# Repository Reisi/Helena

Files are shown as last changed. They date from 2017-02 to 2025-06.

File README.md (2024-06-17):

# Helena

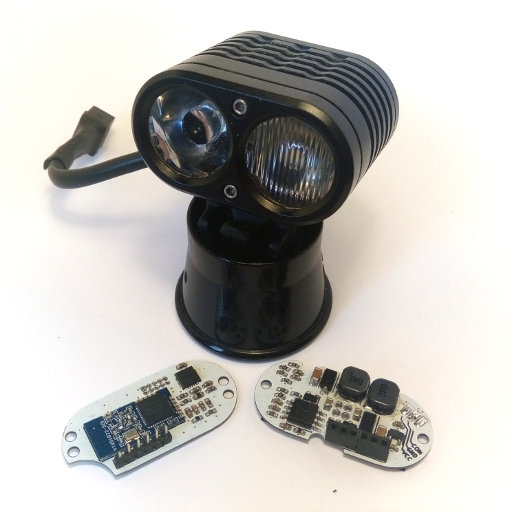
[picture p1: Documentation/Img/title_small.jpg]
Helena
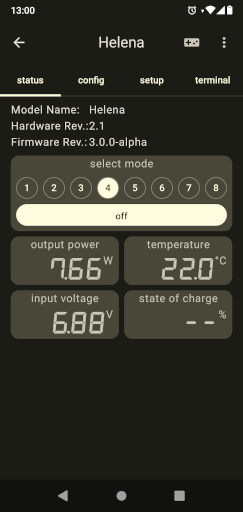
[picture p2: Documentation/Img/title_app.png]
app
 

Helena is an alternative driver for the Yinding or KD2 Headlight Cycling Lamp.

## Main Features

- Two independant 3A Step-Down current converters.
- Bluetooth connectivity for remote control, configuration and lamp-to-lamp connection.
- Linear power reduction at low battery and high temperature.
- Standby current less than 150µA.
- Supports 1 (one LED), 2 (one or two LEDs) or 3 (up to three LEDs in series) cell Li-Ion battery.
- An integrated motion sensor to control the output current to reduce glare when looking down.
- A multi-functional com pin, can be used for wired communication or an external button.

## License

This project is licensed under the BSD-2-clause License - see the [license.txt](license.txt) file for details

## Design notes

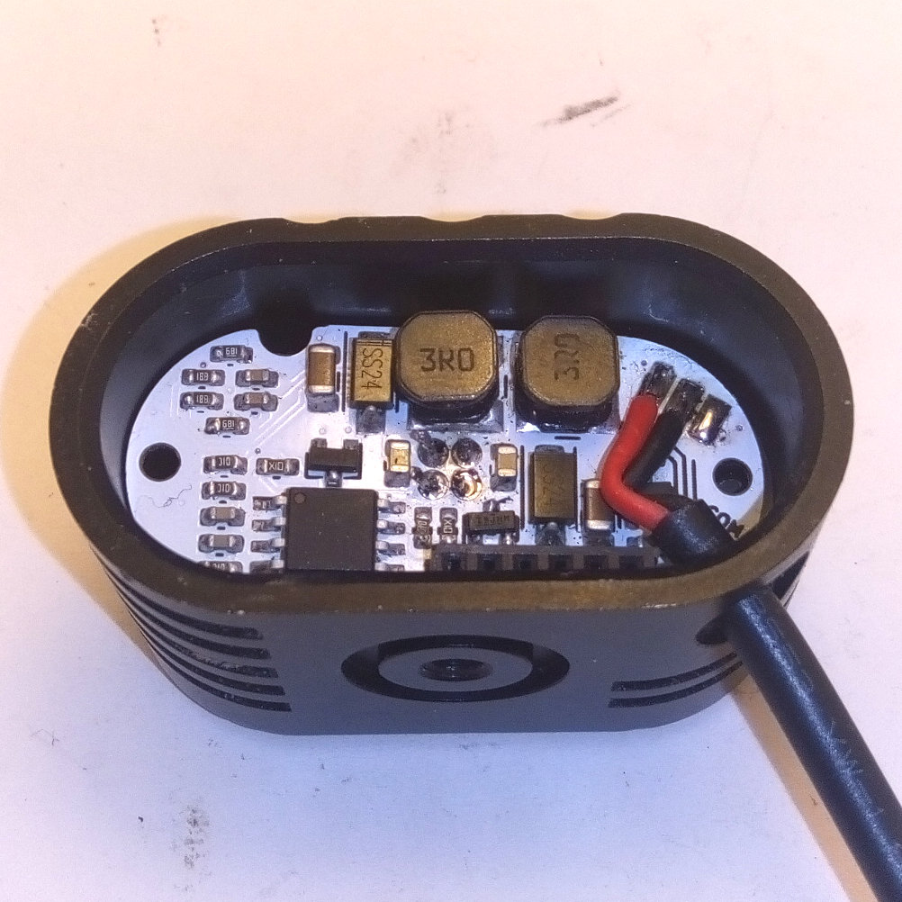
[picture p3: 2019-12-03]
Documentation/Img/inst_YDfull_04.jpg

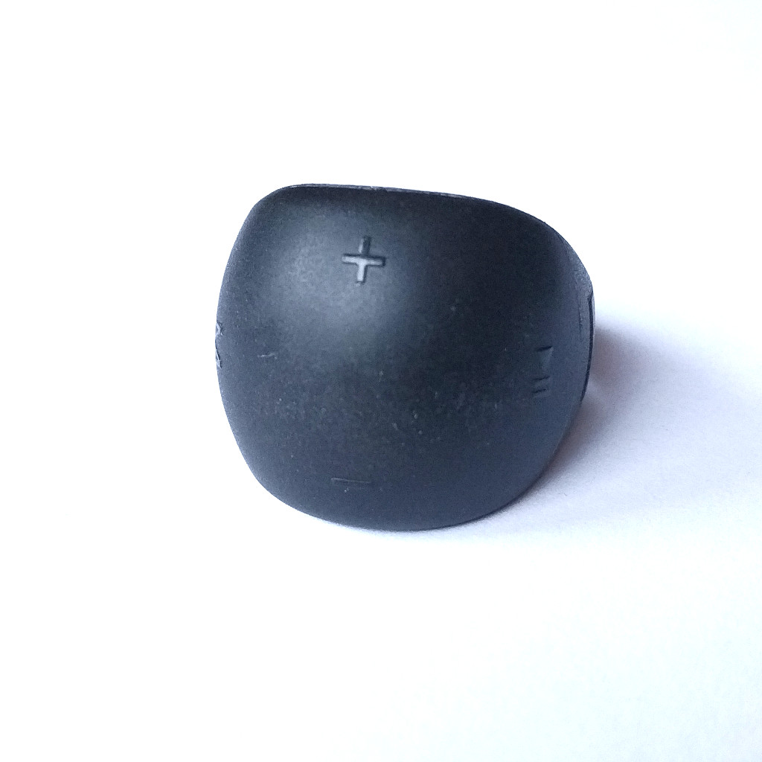
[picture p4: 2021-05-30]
Documentation/Img/R51.jpg

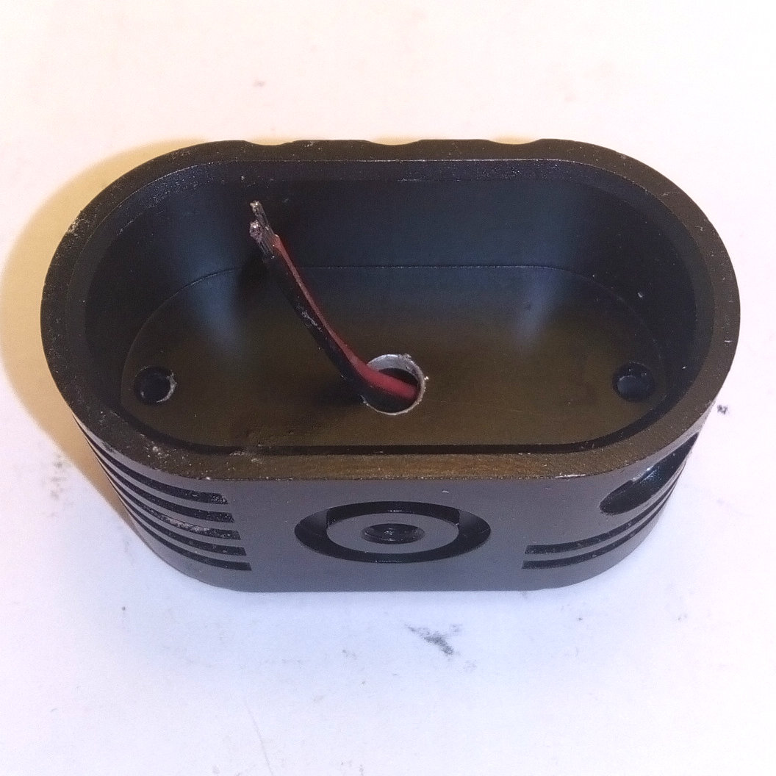
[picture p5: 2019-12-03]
Documentation/Img/inst_YD_01.jpg

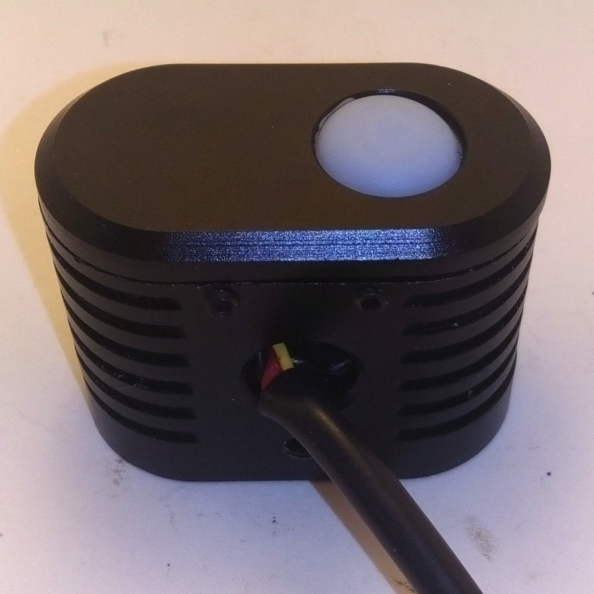
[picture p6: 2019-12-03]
Documentation/Img/inst_KD_06.jpg

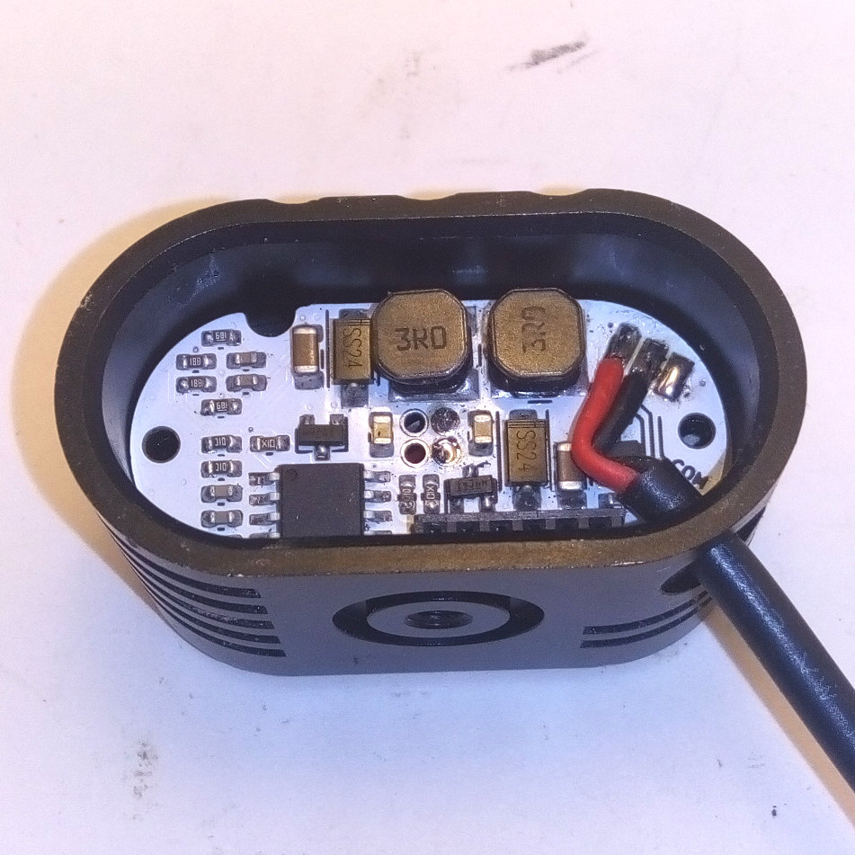
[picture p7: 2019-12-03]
Documentation/Img/inst_YD_03.jpg

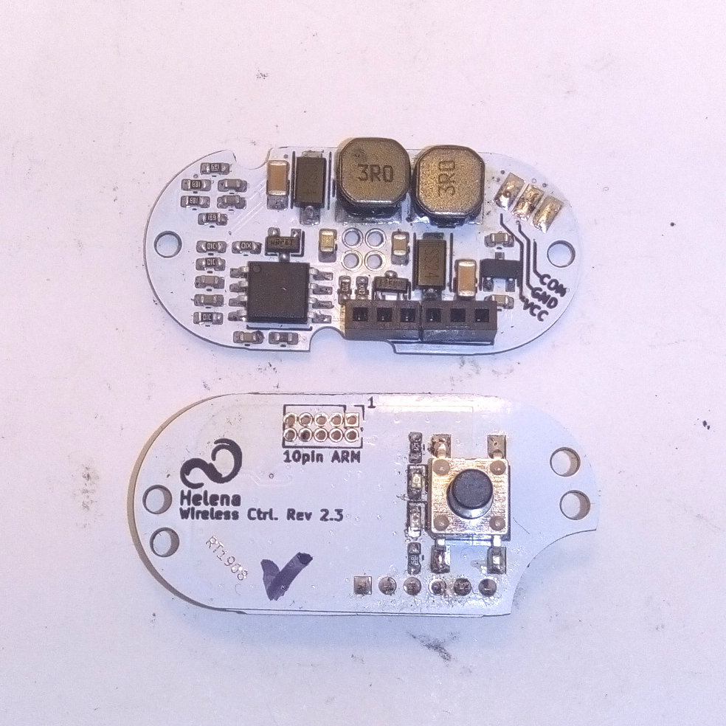
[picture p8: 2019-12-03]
Documentation/Img/inst_con_01.jpg

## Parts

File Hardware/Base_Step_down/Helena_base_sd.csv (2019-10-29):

Id | Designator | Package | Quantity | Designation | Reichelt ordering | MPN
1 | R10,R1,R6,R13,R14 | R_0603_1608Metric | 5 | 10k | RND 0603 1 10K
2 | Q3,Q4,Q6,Q7 | SOT-23 | 4 | IRLML0030 | IRLML 0030
3 | C2,C3,C7,C11,C13,C4 | C_0603_1608Metric | 6 | 100n | X7R-G0603 100N
4 | R4,R12 | R_0603_1608Metric | 2 | 680 | RND 0603 1 680
5 | D5 | SOT-23 | 1 | BAT54A | BAT 54A SMD
6 | L2,L1 | Choke_SMD_Fastron_242418_FPS | 2 | 3u-18 | L-242418FPS 3,0µ
7 | U3 | SOIC-8_5.23x5.23mm_P1.27mm | 1 | ATTINY85-S | ATTINY 85-20 SU
8 | R9,R2,R7 | R_0603_1608Metric | 3 | 10 | RND 0603 1 10K
9 | C10,C12 | C_0603_1608Metric | 2 | 2u2/16 | X5R-G0603 2,2/16
10 | Q1,Q5 | SOT-23 | 2 | BC857C | BC 857C SMD
11 | C8,C6 | C_1206_3216Metric | 2 | 10u/16 | KEM X7R1206 10U
12 | P2,P3,P1 | 1,5x3mm_SMD | 3 | CONN_01X01
13 | REF**,REF** | MountingHole_2.2mm_M2 | 2 | MountingHole_2.2mm_M2
14 | P4 | Pin_Header_Straight_1x06_2.00_Pitch | 1 | CONN_01X06 | MPE 156-1-007
15 | P5,P6,P7,P8 | MILLMAX_5660 | 4 | CONN_01X01 |  | 0660-0-15-15-30-27-10-0
16 | G*** | Helena_5,0x4,1mm | 1 | LOGO
17 | C1,C14 | C_0603_1608Metric | 2 | 22n | X7R-G0603 22N
18 | C5,C9 | C_0805_2012Metric | 2 | 10u/16 | X5R-G0805 10/16
19 | D1,D4,D7 | SOT-23 | 3 | 3V3 | SMD ZD 3,3
20 | D2 | SOT-23 | 1 | 18V | SMD ZD 18
21 | D3,D6 | D_SMA | 2 | SK24A | SK 24A SMD
22 | FB1 | L_0603_1608Metric | 1 | FB | BLM18PG 331
23 | Q2 | SOT-23 | 1 | BSS138 | BSS 138 SMD
24 | R3 | R_0603_1608Metric | 1 | 4k7 | RND 0603 1 4,7K
25 | R5,R11 | R_0603_1608Metric | 2 | 1k5 | RND 0603 1 1,5K
26 | R8 | R_0603_1608Metric | 1 | 330 | RND 0603 1 330
27 | U1 | MSOP-8_3x3mm_P0.65mm | 1 | MCP6482 | MCP 6482-E/MS
28 | U2 | SOT-23W | 1 | MCP1703CB | MCP 1703T-3302E

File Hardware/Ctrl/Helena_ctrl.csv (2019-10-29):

Id | Designator | Package | Quantity | Designation | Reichelt ordering | MPN
1 | SW1 | JTP-1138EM | 1 | SW_PUSH | TASTER 9314
2 | U1 | QFN-24-1EP_4x4mm_Pitch0.5mm | 1 | MPU-6050 |  | MPU-6050
3 | A1 | WT51822-S4AT | 1 | nrf51822-04AT_Module |  | WT51822-S4AT
4 | REF**,REF**,REF**,REF** | MountingHole_2.2mm_M2 | 4 | MountingHole_2.2mm_M2
5 | G*** | Helena_5,0x4,1mm | 1 | LOGO
6 | C1 | C_0603_1608Metric | 1 | 2u2/16 | X5R-G0603 2,2/16
7 | C2,C13,C15,C16 | C_0603_1608Metric | 4 | 100n | X7R-G0603 100N
8 | C14 | C_0603_1608Metric | 1 | 10n | X7R-G0603 10N
9 | C17 | C_0603_1608Metric | 1 | 2n2 | X7R-G0603 2,2N
10 | D1 | D_0603_1608Metric | 1 | LED_RED | LED EL 0603 RT
11 | D2 | D_0603_1608Metric | 1 | LED_BLUE | LED EL 0603 BL
12 | FB1,FB2 | L_0603_1608Metric | 2 | FB | BLM18PG 331
13 | J1 | PinHeader_1x06_P2.00mm_Vertical | 1 | CONN_01X06 | MPE 150-1-010
14 | J2 | PinHeader_2x05_P1.27mm_Vertical | 1 | CONN_02X05
15 | R1 | R_0603_1608Metric | 1 | 470k | RND 0603 1 470K
16 | R2 | R_0603_1608Metric | 1 | 100k | RND 0603 1 100K
17 | R3,R5 | R_0603_1608Metric | 2 | 1k5 | RND 0603 1 1,5K
18 | R4 | R_0603_1608Metric | 1 | 680 | RND 0603 1 680
19 | R7 | R_0603_1608Metric | 1 | 120 | RND 0603 1 120

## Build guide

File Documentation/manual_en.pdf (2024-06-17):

# Helena

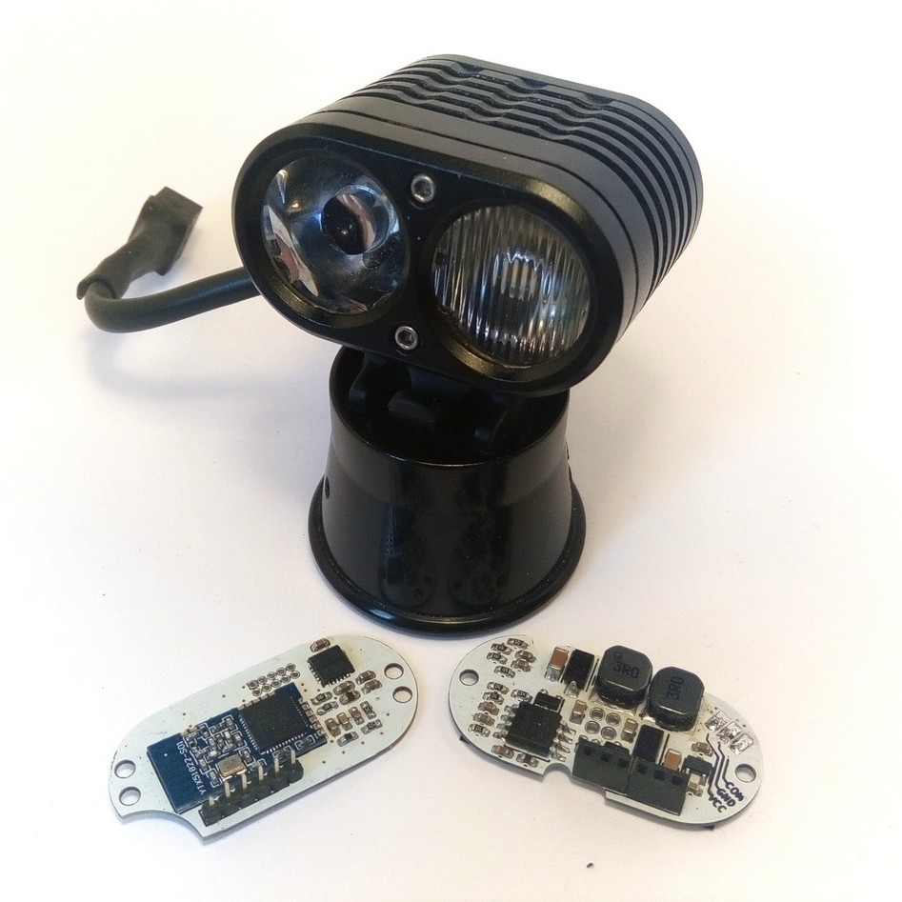
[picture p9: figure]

# User Manual

Helena User Manual

## 1 Preface

Helena is an alternative driver for the popular Yinding or KD2 Headlight Cycling Lamp with following features:
- Two independent 3A Step-Down constant current sources, each capable of driving two white LEDs in series. The intended setup is one Cree XHP50 LED equipped with a flood optic and one Cree XHP35 6V equipped with a spot optic.
- Integrated motion sensor to drive the LEDs in dependency of the head inclination, resulting a nearly constant brightness level, no matter if you're looking down or straight forward.
- Bluetooth interface for wireless remote control, lamp daisy-chaining and Smartphone based configuration.
- Integrated temperature regulation to prevent lamp from overheating.
- Smooth output power reduction when battery is low.
- Low standby current (less than 100µA).
- Works with input voltages between 3V and 4.25V (only 1 LED per current source), 6V and 8.5V and between 9V and 12.75V (max. output current is limited to 2.4A).

2/22

Helena User Manual

## Index

3/22

Helena User Manual

## 2 Installation

## 2.1 Connections

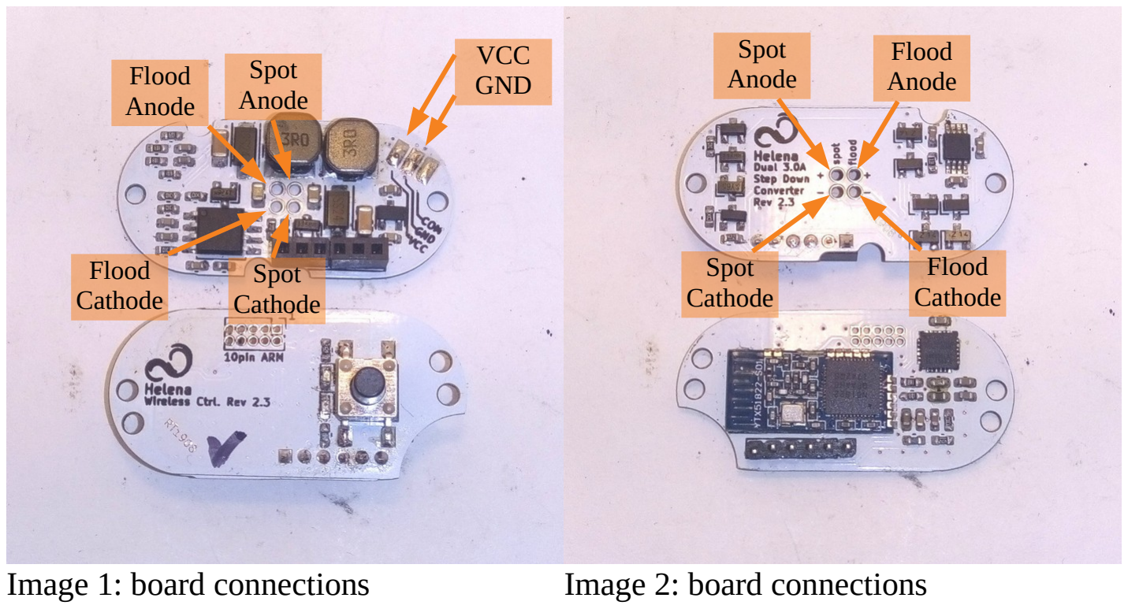
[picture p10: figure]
Flood Cathode; Flood Anode; Spot Cathode; Spot Anode; VCC GND

4/22

Image 1: board connections | Image 2: board connections

Helena User Manual

## 2.2 Driver Swap for KD2

Step 1.Disassemble lamp and remove old driver. Mount LED board witch the

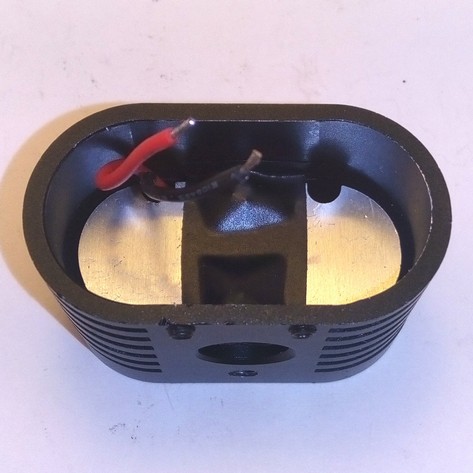
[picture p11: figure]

notches facing to the top and route both cables through the left one. Then cut the cables to a length of 20-25mm and cover the screws with electric tape.

Step 2.Connect the LED cables to the spot driver output of the LED driver. Route the cables as shown in the image.
Step 3.Attach the power cable (and optionally the communication line). Route the cables along the board-to-board connector and use the notch next to it to lead it through the opening.

5/22

Image 3: LED board
preparations

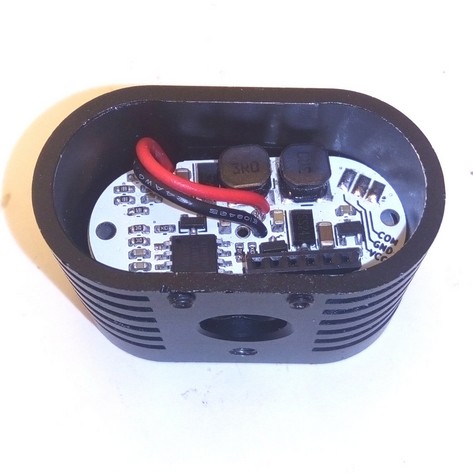
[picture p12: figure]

Image 4: LED connection

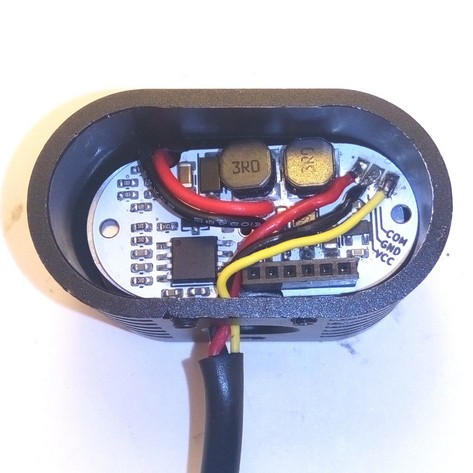
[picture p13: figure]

Image 5: power cable
routing

Helena User Manual

Step 4.Mount the controller board to the lid.
Step 5.Put a pair of tweezers, zip ties, toothpicks or a similar object between the LED- and driver board to lift it a couple of millimeters, then put the lid on and.
Step 6.When the connector fits properly, remove the tweezers, close the lid and you are done.

6/22

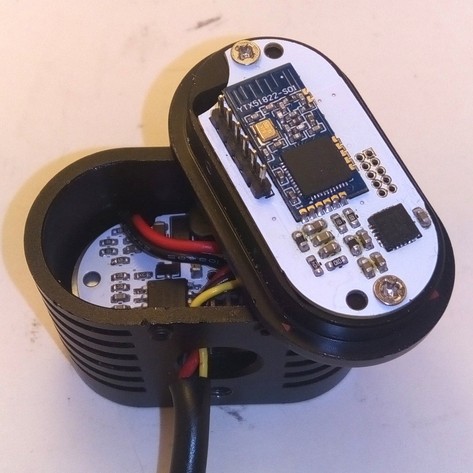
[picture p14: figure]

Image 6: mounted
Controller board

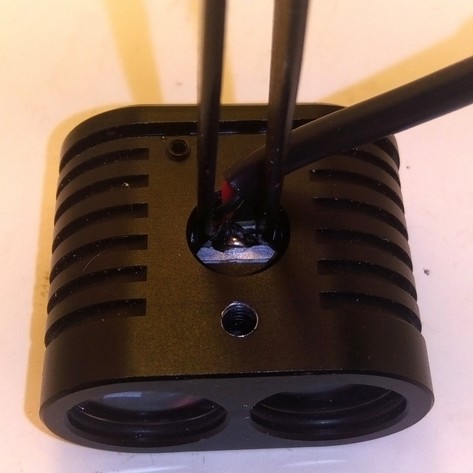
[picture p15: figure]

Image 7: Lift driver board for proper connection

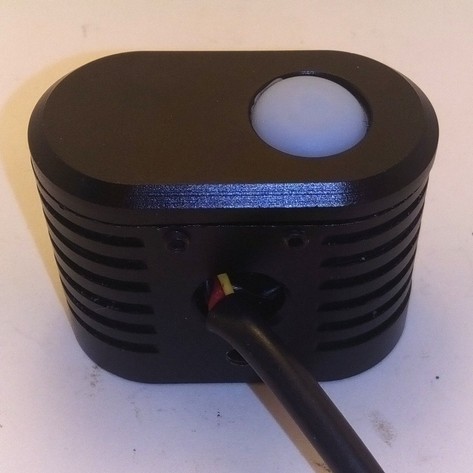
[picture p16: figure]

Image 8: closed lid

Helena User Manual

## 2.3 Driver Swap for Yinding

Step 1.Disassemble lamp and remove old
driver. Cut the cables to a length of 20-
25mm.
Step 2.Attach the power cable (and optionally the communication line) Don’t forget to run the cable through the opening in the lamp body.
Step 3.Now attach the cables from the LED board to the spot output. Connect them from the bottom side.

7/22

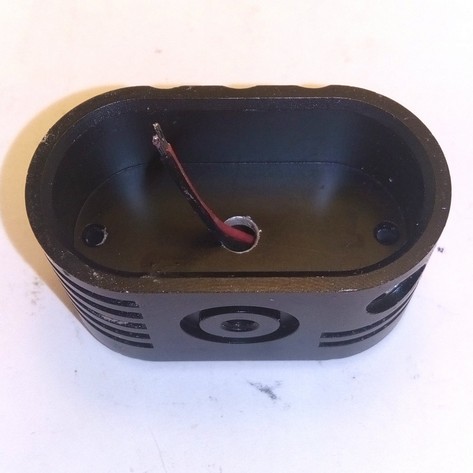
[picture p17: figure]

Image 9: prepared LED
cables

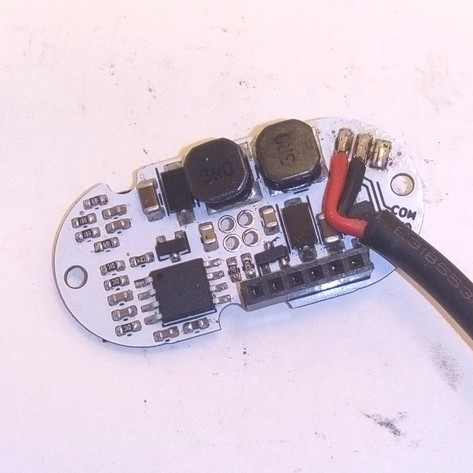
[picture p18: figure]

Image 10: attached power
cable

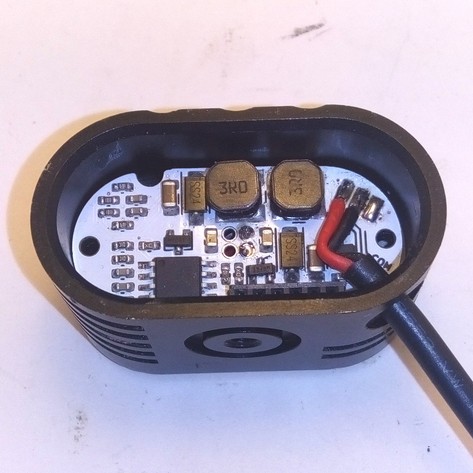
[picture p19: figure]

Image 11: attached LED
cables

Helena User Manual

Step 4.Mount the controller board to the lid.
Step 5.Close the lid and reassemble the lamp.

8/22

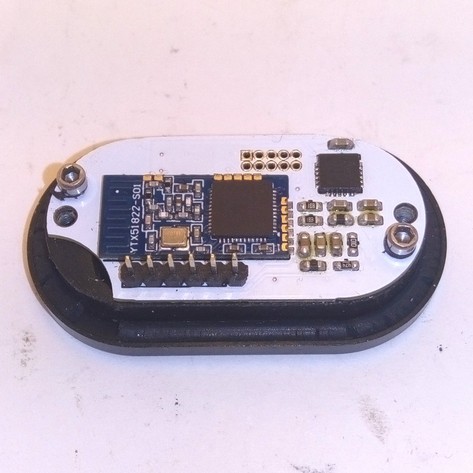
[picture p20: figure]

Image 12: mounted
Controller board

Helena User Manual

## 2.4 Full conversion for Yinding

Step 1.Prepare LED boards by attaching
cables and cutting them to a length of
25-30mm.
Step 2.Attach the power cable (and optionally the communication line) Don’t forget to run the cable through the opening in the lamp body.
Step 3.Route the LED boards cables through the inner hole.

9/22

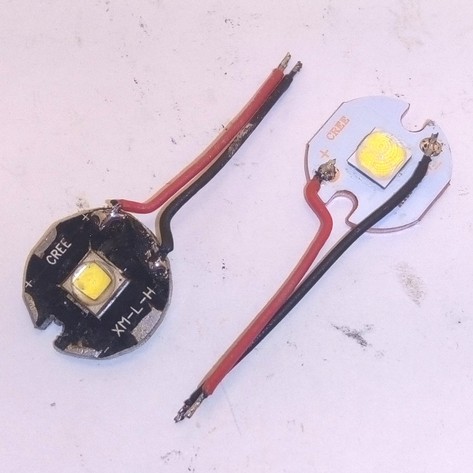
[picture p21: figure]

Image 13: prepared LED
boards

Image 14: attached power
cable

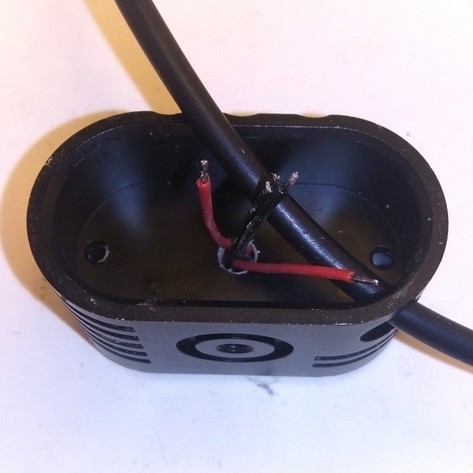
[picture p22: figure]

Image 15: cable routing

Helena User Manual

Step 4.Now attach the cables from the bottom

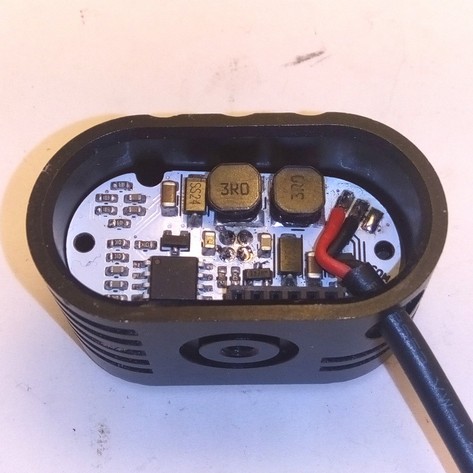
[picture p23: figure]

side. Solder the cables of the XHP50 to the flood output and the cables of the XM-L to the spot output.

Step 5.Mount the controller board to the lid and close the lid.
Step 6.Flip the lamp around and tighten the screws to secure the lid and LED

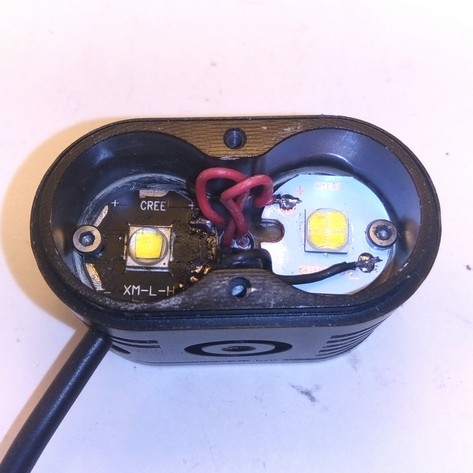
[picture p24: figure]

boards. Position the XHP50 board a bit to the top and the XM-L board a bit to the bottom.

10/22

Image 16: attached LED
boards cables

Image 17: mounted
Controller board

Image 18: LED boards
alignment

Helena User Manual

Step 7.Insert the lenses and use some spacers to tilt the spot lens upwards and the flood lens downwards. The spacers should have a height of 0.7-1.0mm, a quartered O-Ring works fine.
Step 8.Finally mount the lens cover.

11/22

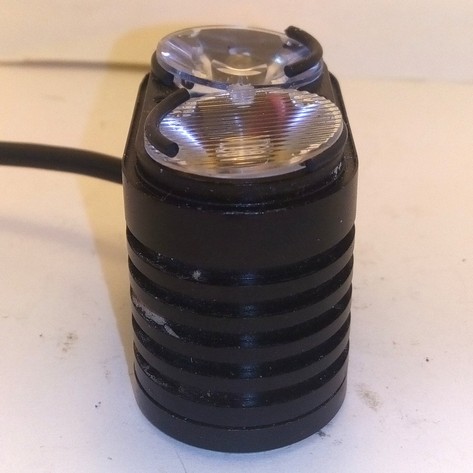
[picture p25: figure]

Image 19: tilted lenses

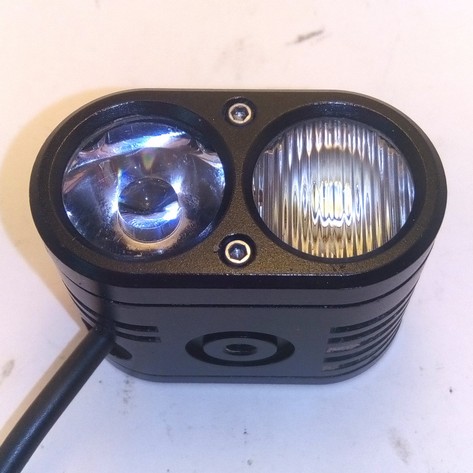
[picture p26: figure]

Image 20: reassembled

Helena User Manual

## 3 Usage

## 3.1 Modes and Groups

Helena has 8 individual configurable modes, which can be organized in different groups.

### 3.1.1 Preferred Mode

One of the 8 available modes can be selected as the preferred mode. If no mode is selected to be the preferred mode, the lamp will shut off whenever the preferred mode is selected. If one mode is selected as the preferred mode the lamp will shut off, if it already is in the preferred mode. Otherwise it will jump to the preferred mode.

### 3.1.2 Temporary Mode

One of the 8 available modes can be selected as a temporary mode. If a mode is selected as temporary mode, it is possible to jump directly into this mode. When leaving the mode, Helen jumps back to the previously used mode.

### 3.1.3 Off Mode

One of the 8 available modes can be selected as the off mode. If a mode is selected as off mode, this mode will be used when the lamp is shut off. When the lamp enters stand-by mode (after three minutes without movement) it will completely shut off.

12/22

Helena User Manual

## 3.2 Remote Connection

Helena can manage up to 3 connections, 2 as a central (e.g. a remote control or another lamp) and 1 as peripheral (e.g. a smart phone or another lamp).
Although it is possible to pair with several remote controls, it is not possible to connect to more than one remote control simultaneously. If two lamps are connected to each other, the lamp with the peripheral connection will break its connection with a remote control and won’t reconnect as long as it is connected with the other lamp.

### 3.2.1 Central connection

To initiate a connection as central (e.g. if you want to connect to a remote control or initiate a central connection with another lamp), you have to
- shut of Helena,
- make sure, that all other unwanted compatible devices are shut of or out of range,
- press Helena’s button for at least 2 sec.
Helena will indicate the search process with a fast blinking blue status LED. As soon as a connection is established the blue status LED will be constantly on. If no device is found within 30 sec. the lamp will stop searching and starts a 30 sec. window where it is open for peripheral connections (see next chapter).

13/22

Helena User Manual

This procedure is only necessary for the initial connection. The lamp will store all necessary information and automatically reconnect if the device is available.

### 3.2.2 Peripheral connection

To initiate a connection as peripheral (e.g. if you want to connect to a smartphone or initiate a peripheral connection with another lamp), you have to
- shut of Helena,
- make sure, that all other unwanted compatible devices are shut of or out of range,
- press Helena’s button for at least 2 sec until the blue led blinks fast,
- wait 30 sec until the blue led stops fast blinking.
Now you can start the connection procedure on the central device. This procedure is only necessary for the initial connection. The lamp will store all necessary information and you can establish future connection as soon as Helen is powered on.

## 3.3 Button Control

There are 4 button control commands:
- next mode:
This command jumps to the next mode.
If the ignore flag for this mode is selected, it will be skipped.

14/22

Helena User Manual

If the last mode within a group is reached, it will roll over to the first mode.
If the light is currently off it jumps to the first mode.
- next group:
This command jumps to the next group.
If the group only contains ignored modes, it will be skipped. If the current group is the last group, this command will jump to the first group.
If the light is currently off, it jumps to the first mode in the second group.
- preferred mode:
If the preferred mode is not set, the light will shut off.
If the preferred mode is set, the light will jump directly to the preferred mode.
If the light is already in the preferred mode, it will shut off.
- temporary mode:
If the temporary mode is set, the light will jump into the temporary mode and jumps back to the previous mode.

### 3.3.1 Integrated button

- short click:
next mode command
- long click:
next group command

15/22

Helena User Manual

- press and hold > 2 sec., light is on: preferred mode command
- press and hold > 2 sec., light is off:
initiate connection procedure
hold button again for 2 sec. to delete all bluetooth bonding data
- press and hold > 10 sec., light is off:
initiate a factory reset

### 3.3.2 External button (if available)

- short click:
next mode command
- long click:
next group command
- press and hold > 2 sec.:
preferred mode command

### 3.3.3 Xiaomi Yi remote control

- main button, short click:
next mode command
- main button, press and hold > 0.5 sec.:

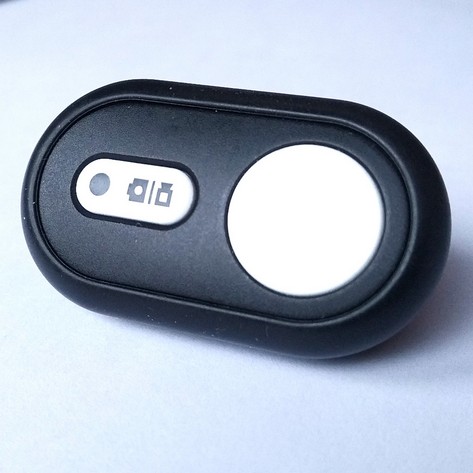
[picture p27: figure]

enter temporary mode as long as button is pressed
- secondary button, short click:
next group command

16/22

Image 21: Xiaomi Yi RC

Helena User Manual

- secondary button, press and hold > 0.5 sec.: preferred mode command

### 3.3.4 Pearl/Auvisio remote control

- next track button, short click:
next mode command
- previous track button, short click:
previous mode command
- volume up button, short click: next group command
- volume down button, short click: previous group command
- play/pause button, short click:
preferred mode command

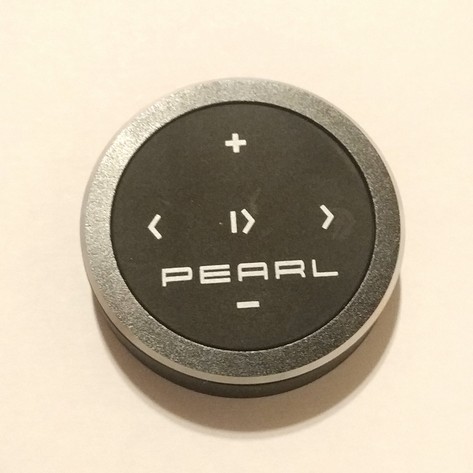
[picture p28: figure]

## 3.4 Remote Synchronization

If Helena is connected to another lamp, both lamps will synchronize their current mode. This means if one light receives a button command, it will change its mode according to the description in the previous chapter and then relay this new mode (the number, not the configuration!) to the other lamp.
This lamp will then also jump into this mode, nevertheless if this mode is used or not. With this behavior it is possible to generate configurations where one lamp is on and the other not.

17/22

Image 22: Pearl/Auvisio
remote

Helena User Manual

## 3.5 Status LED

Helena is equipped with a red and blue status LED, which is visible through the transparent button cap.
The blue LED gives information about the wireless connection. If is on, Helena is connected to a remote or another lamp. A fast blinking indicates, that Helena is searching for any compatible device. A slow blinking blue LED indicates, that Helena is searching for a already known device.
The red on turns on whenever the output is limited due to high temperature or dropping input voltage.
When Helena enters standby mode, the Status LED is shut off for minimum current consumption (but an established connection or the scanning for a known device will not be stopped).

18/22

Helena User Manual

## 4 Configuration

## 4.1 Connecting with the App

To connect to your lamp plug in the battery,
open the App on your phone and press the
SEARCH button. The App will then search and connect to all compatible lamps in range. Tap on the the light you want to configure.

19/22

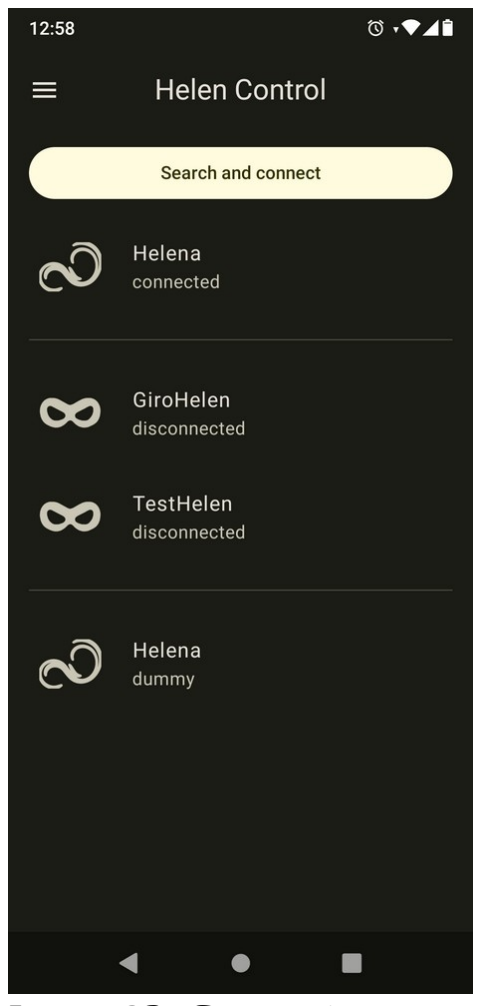
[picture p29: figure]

Image 23: Connecting

Helena User Manual

## 4.2 Light status

The STATUS page
gives you information
about the current state
of the lamp.
If you tap at the control
icon in the top bar you
can also select any of
the light modes or shut
it off.
You can also switch
between the Expert
Mode and two profiles
for easier configuration
and setup (Helena for
a full conversion, or
SimpleHelena if

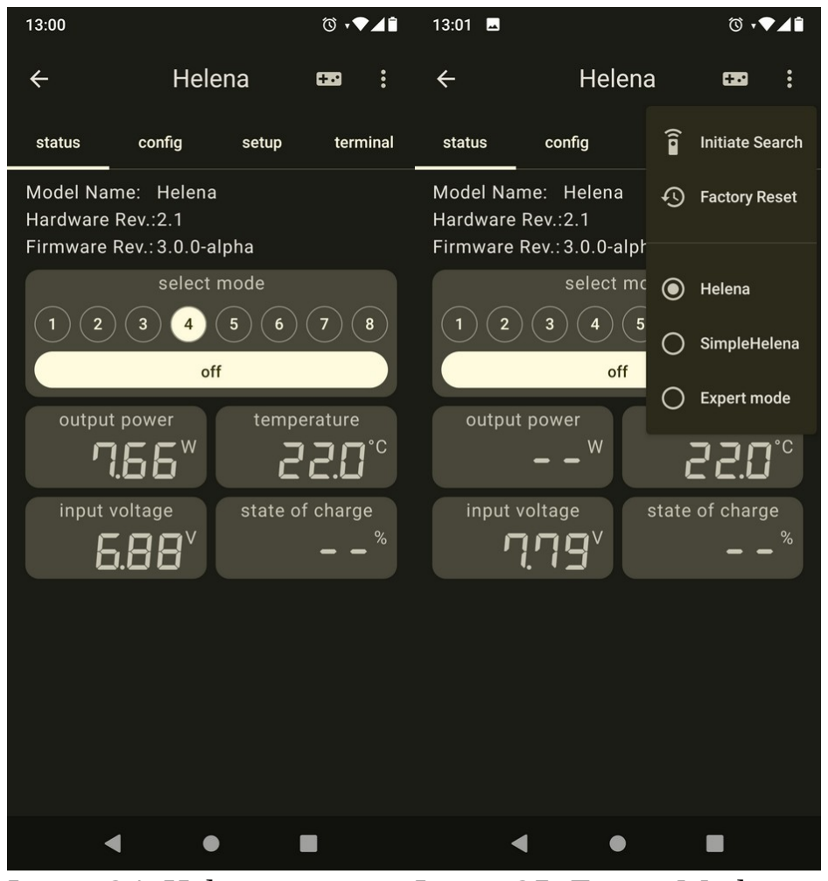
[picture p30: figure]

you just swapped the driver)

20/22

Image 25: Expert Mode or
profile selection

Image 24: Helena status

Helena User Manual

## 4.3 Configuration

On the CONFIG page
you see an overview of
your modes and the

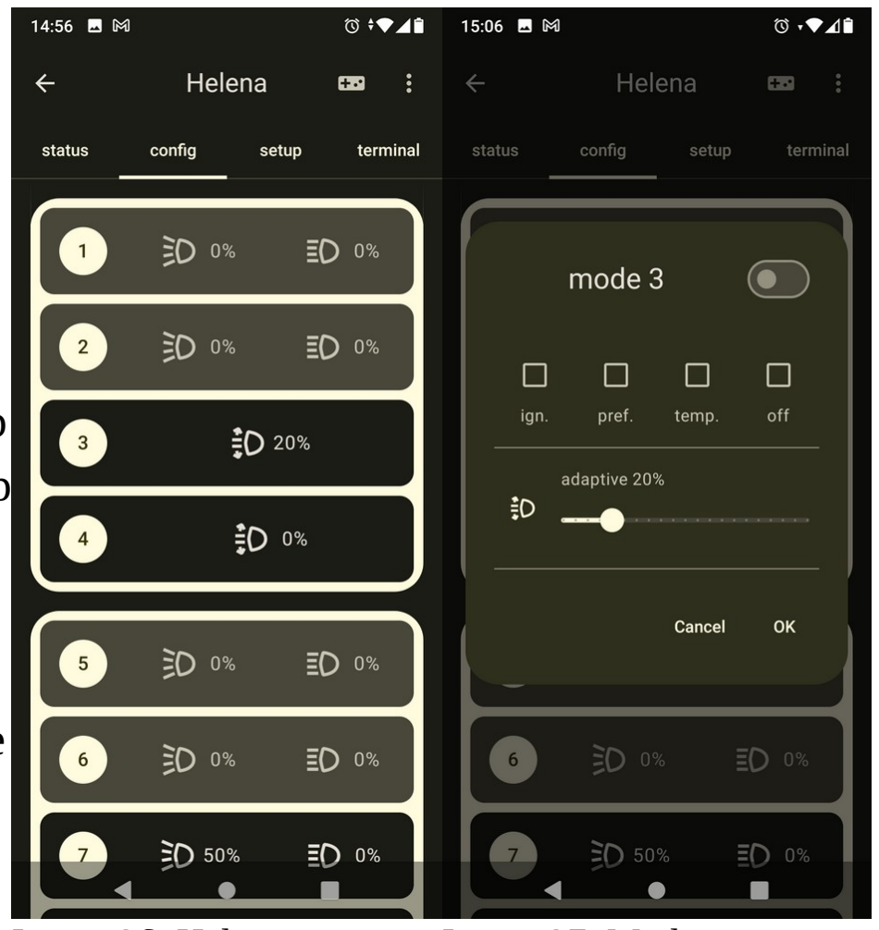
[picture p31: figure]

group arrangements. To
change the group
arrangement simply
drag and drop the group
dividers. To add a group
you can drag and drop
from the top or bottom.
To change a mode
configuration tap on the
mode. There you can
select if the mode
should be ignored, used
as preferred, temporary
or off mode, you can select the intensity of the light and if the motion sensor should be used for to adjust the light depending on your head inclination.

21/22

Image 27: Mode
configuration

Image 26: Helena
configuration

Helena User Manual

## 4.4 Setup

On the SETUP page you can select how to use the the communication pin. If you selected the Expert Mode you can also specify the setup of both LED channels.

22/22

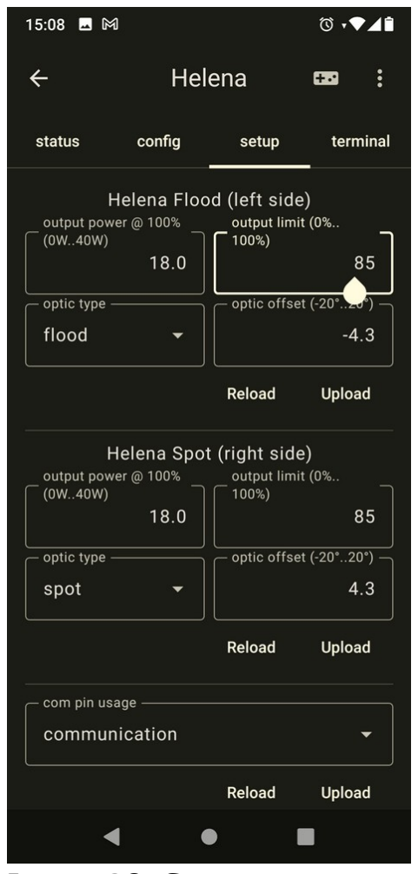
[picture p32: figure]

Image 28: Setup

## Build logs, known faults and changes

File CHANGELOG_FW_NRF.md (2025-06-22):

# Changelog
All notable changes to the NRF51 firmware will be documented in this file.

The format is based on [Keep a Changelog](https://keepachangelog.com/en/1.0.0/)

## [3.0.1] - 2025-06-22
### Fixed
- mode relay result in hard fault if made change initiated through com interface.
  (temporarily fixed by decreasing com interrupt level, but better solution is to 
  keep interrupt level high and relay in main context)
- increased transmit power

### Known Issues
- bootloader disconnects at about 20% when started in main application

## [3.0.0-alpha] - 2024-06-17
### Changed
v3 is not a continued development, it is the nrf52 based helen project ported to the nrf51.
- added support for a second central connection
- channels can be configured completely individual, making the need for different firmware variants obsolete
- the com pin can alternatively be used for an external button
- limiter is now prioritized, with spot having a higher priority as the flood

## [2.3.1] - unreleased
### Added

### Changed
- mode changes from com will now be relayed

### Removed

### Fixed
- fixed wrong version build format
- database discovery will be restarted if first attempt is busy

### Known Issues
- daisy chain: if quickly changing mode twice, the second change may not be 
  executed by the remote lamp.

## [2.3.0] - 2022-07-24
### Added
- support for billy base led driver
- bonding required to change settings (only for release)
- support for avisio/pearl remote control

### Changed
- group size can be configured individually

### Removed

### Fixed
- missing length checking for debug commands
- false decoding for com master messages
- going backwards to modes and groups malfunction
- missing line breaks in debug calibration section
- watchdog reset if transferring long error log over BLE

### Known Issues
- daisy chain: if quickly changing mode twice, the second change may not be 
  executed by the remote lamp.

## [2.2.1] - 2021-05-30
### Added

### Changed

### Removed

### Fixed
- wrong placed error check on data storage
- billina not transmitting correct high beam intensity
- features incomplete
- rounding error at intensity converting
- wrong error code if sensor offset not done yet

### Known Issues
- daisy chain: if quickly changing mode twice, the second change may not be 
  executed by the remote lamp.

## [2.2.0] - 2021-05-02
### Added
- improved status led, blue blinking while scanning, red and blue active works
  now for HWREV22 and HWREV23, too.
- added battery SOC and taillight power to measurement notification
- temporary mode
- hold button for 10 sec. (from off state) will initiate factory reset
- SOS mode for Helena, to enter press button for 10 sec. from an active mode
- support for 1- and 3-cell li-ion batteries.

### Changed

### Removed

### Fixed
- BLE_GATT_STATUS_ATTERR_CPS_PROC_ALR_IN_PROG leading to reset
- automatic led count detection might deliver wrong led count

### Known Issues
- daisy chain: if quickly changing mode twice, the second change may not be 
  executed by the remote lamp.

## [2.1.0] - 2021-04-18
### Added
- support for R51 "The Lord of Rings" Remote Control

### Changed
- behavior of preferred mode
- removed service discovery for HID service and replaced it with hardcoded 
  presets.

### Removed

### Fixed
- several fixes concerning data storage

### Known Issues
- automatic led count detection might deliver wrong led count

## [2.0.2] - 2021-03-30
### Added

### Changed

### Removed

### Fixed
- mode request not using full message length
- wrong flags in measurement data

### Known Issues
- automatic led count detection might deliver wrong led count

## [2.0.1] - 2021-03-28
### Added

### Changed

### Removed

### Fixed
- changing between helena and billina firmware now possible without loss of 
  settings

### Known Issues
- automatic led count detection might deliver wrong led count

## [2.0.0] - 2021-03-25
### Added
- added build target for "Billy" mode, a setup especially for bike lights 
  without pitch compensation, but separate driver current for low and high 
  beam.

### Changed
- light control services was modified and extended to meet requirements for 
  bicycle light

### Removed

### Fixed
- update from version 0.X will not end in an error loop anymore

### Known Issues
- when changing for helena to billina firmware (and vice versa) settings will 
  reset to defaults
- automatic led count detection might deliver wrong led count

## [1.1.0] - 2020-03-11
### Added
- re-implemented reset survive (lamp keeps its mode even if it is reset by 
  watchdog)
- release version

### Changed
- reworked debug interface

### Removed

### Fixed

### Known Issues
- Update from version 0.X might result in an infinite error loop. 
  Workaround: flash back to old firmware and perform factory reset, then update
  will work
- automatic led count detection might deliver wrong led count

## [1.0.0] - 2019-12-03
### Added
- this changelog
- Daisy chain feature, lamp cannot only connect to remote but to other light, 
  too. Changes to another mode (either by remote or button) are relayed to 
  other connected lamps, this work bidirectional
- expanded light setups and added the ability to control an external taillight
  and brake indicator using the wired communication interface
- automatic wake-up from STANDBY mode when moving to speed up (re-)connection 
  to remote
- preferred mode added, when set to a valid mode, lamp will start into this 
  mode and, if shutdown via remote, return to this mode first
- option to calibrate driver board over debug interface

### Changed
- Switched mode configuration from enumeration to flag based setup
- changed temperature limiter to start later at 59°C (previous started at 47°C)
- changed voltage limiter to a two slope curve, to provide more output power at
  low battery temperatures
- user manual and quick start guide are adapted to flag based setup 
  configuration
- indicator leds are shut off in STANDBY mode to minimize current consumption
- debug interface changed, no "get error log" message necessary anymore, log is
  enabled automatically with enabling notifications

### Removed

### Fixed
- device will not bond to remote (had no effect, because remote initiated 
  bonding)
- garbage collection not working properly resulting in a lockup where no more 
  write operations are working.

### Known Issues
- Update from version 0.X might result in an infinite error loop. 
  Workaround: flash back to old firmware and perform factory reset, then update
  will work

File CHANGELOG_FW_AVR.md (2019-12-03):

# Changelog
All notable changes to the AVR based LED driver board firmware will be 
documented in this file.

The format is based on [Keep a Changelog](https://keepachangelog.com/en/1.0.0/)

## [Unreleased]
### Added
### Changed
### Removed
### Fixed
### Known Issues

## [1.2] - 2019-12-03
### Added
- this changelog
- calibration option through I2C interface

### Changed

### Removed

### Fixed

### Known Issues

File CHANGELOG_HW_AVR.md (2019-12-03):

# Changelog
All notable changes to the AVR based LED driver board hardware will be 
documented in this file.

The format is based on [Keep a Changelog](https://keepachangelog.com/en/1.0.0/)

## [Unreleased]
### Added
### Changed
### Removed
### Fixed
### Known Issues

## [2.3] - 2019-12-03
### Added
- this changelog
- added notches for optimized cable routing for KD2 lamps
- changed to IPC-7351B footprints

### Changed

### Removed

### Fixed

### Known Issues

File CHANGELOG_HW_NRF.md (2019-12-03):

# Changelog
All notable changes to the NRF51 based controler driver board hardware will be 
documented in this file.

The format is based on [Keep a Changelog](https://keepachangelog.com/en/1.0.0/)

## [Unreleased]
### Added
### Changed
### Removed
### Fixed
### Known Issues

## [2.3] - 2019-12-03
### Added
- this changelog
- changed to IPC-7351B footprints

### Changed

### Removed

### Fixed

### Known Issues
- naming format, should be 2.2.1 or 2.2a. But 2.3 is already printed on boards

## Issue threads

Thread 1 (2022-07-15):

Einlesen von der Spannung am nrf51822

StefStein, 2022-07-15:
Servus Reisi,
bei der Helena hast Du im Code beim Einlesen der Spannung ein Teilungsverhältnis von 1/3 stehen. Die Beschaltung im Ctrl-Board ist 1/6 (100K + 470K).
Die App gibt bei anliegenden 8V im Feld 0,2V an.
Ich vermute, daß dadurch (trotz Aktivierung in der App) der µP an beiden Ausgängen "LOW" anlegt.
Somit ergibt sich an den beiden LEDs (Kathode und Anode von Spot und Flood) jeweils 8V -> es leuchtet nichts.
Kannst Du bitte mal helfen
Danke
Stefan

Reisi, 2022-07-16:
Servus Stefan,
ich denke nicht, dass hier ein Software Problem vorliegt, da die externen und internen Spannungsteiler über das Makro RESULT_IN_MILLIVOLT(x) in der adc.h berücksichtigt werden.
Hast du schon mal einen genaueren Blick auf den 470k Widerstand geworfen? Möglicherweise liegt an dem eine kalte oder gebrochen Lötstelle vor.

Reisi, 2022-07-18:
Achso,
das ist allerdings nur Pin 3 am Modul, am nrf51822 ist das dann P0.01/Pin 5.

Reisi, 2022-07-19:
Ich behaupte nicht, dass die Firmware fehlerfrei ist, aber dieser Fehler tritt momentan nur mit deiner Hardware auf.

Was gibt die App bei der Hardware Rev. aus? Funktioniert die Winkelerkennung?
Möglich wäre es, dass beim Initialisieren das falsche Board erkannt wird und dadurch am falschen Pin gemessen wird.

StefStein, 2022-07-20:
Ich meine nicht, daß Fehler in der SW sind.
Ich hoffe nur auf Ideen an welchen Punkten (auch in der SW) ich die Fehlersuche ansetzen soll.
Ich habe 2 Screenshots von der App angehängt

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

Reisi, 2022-07-20:
gib in der App im Debug Tap mal `errorlog --read` ein, da dürften dann ein paar Fehlermeldungen kommen, da anscheinend auch die I2C Verbindung mit dem Treiber bzw. Beschleunigungssensor nicht funktionieren.

StefStein, 2022-07-20:
soweit wird gelesen:

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

danach bricht die App ab:

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

Reisi, 2022-07-21:
Ok, die abstürzende App muss ich mir mal anschauen.
Den Fehler, den ich erwartet habe ist aber nicht dabei, sondern nur Fehler, die auf eine nicht funktionierende I2C Kommunikation hindeuten.
Hast du dir schon mal die Spannungen an den SDA und SCL Pins angeschaut, liegen da 3,3V an (wenn nicht gerade etwas übertragen wird).
Du kann auch mal versuchen das Controller Board getrennt zu betreiben, also nur GND, 3,3V und optional VCC anzuschließen, wenn der Beschleunigungssensor dann funktioniert liegt das I2C Problem auf der Treiber Platine.

StefStein, 2022-07-22:
Ich habe das Ctrl-Board nur mit 3,3v und GND versorgt
An SDA und SCL liegen 3,3V an (keine Kommunikation)
In diesem Zustand errorlog ausgeführt:
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
App stürzt hier wieder ab

SDA + SCL (Oszi):
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

Nächste Woche schaue ich mir die Pegel von SDA und SCL am SD-Board an (erst getrennt von Ctrl dann verbunden)
Die Pegel sollten im Ruhezustand weiter auf 3,3V liegen (vorausgesetzt die IOs am µC sind nicht auf "LOW" konfiguriert)

StefStein, 2022-07-22:
Die Kalibrierung vom Beschleunigungssensor ist auch hier fehlgeschlagen

Reisi, 2022-07-24:
Ich hab mal versucht die abstürzende App zu reproduzieren, bei mir stürzt immer die Helena ab, und nicht die App. Der Fehler ist aber jetzt behoben.

Hat der Beschleunigungssensor überhaupt nicht funktioniert, also immer konstant 0° angezeigt? Die Kalibrierung kann auch aus anderen Gründen fehlschlagen.

Funktionieren wenigstens die Status LEDs (die sollte blau blinken, wenn nach einer Fernbedienung gesucht wird), bzw. im Bootloader sollte die rote bzw. bei Verbindung die blaue LED leuchten.

StefStein, 2022-08-29:
Der Beschleunigungssensor funktioniert gar nicht.
Die Status LEDs scheinen iO zu sein.

Ich denke ich habe die Ursache gefunden:
**Es ist keine SW auf dem ATtiny85 gelandet**.
Ich habe mir jetzt alle Tools ausgeliehen (JLink+, AVR JTAGICEmk2) -> Ich kann den nrf51822 kpl flashen (Bootloader über nrfjprog und Helena_app.zip über nrfconnect).
Allerdings klappt das Flashen (Bootloader + Appl) beim ATtiny85 gar nicht (Microchip Studio 7 und AVR JTAGICEmk2). Es ist nicht möglich I2C/TWI/PDI als Interface auszuwählen. Ich mache irgendetwas falsch - nur was?

Reisi, 2022-08-29:
Den Attiny programmiert man eigentlich über das ISP Interface, aber ich programmiere die normalerweise vorm einlöten. Im eingebauten Zustand wird das wahrscheinlich nicht funktionieren. Möglicherweise reicht es, wenn man nur den Reset Pin wieder ablötet.
Die Einstellungen für die Fuses findest du [hier](https://github.com/Reisi/Helena/blob/master/HOWTOCOMPILE.md), falls noch nicht gesehen.

StefStein, 2022-08-30:
Ich habe es im eingebauten Zustand, ohne den Reset Pin abzulöten, ausprobiert. Dazu habe ich ergänzend zu den vorhandenen Signalen am 6pol. Stecker den Reset Pin und MISO direkt am ATtiny85 kontaktiert. Es hat funktioniert.
Zuerst den Bootloader und anschliessend die Applikation, dann die Fuses.
Allerdings konnte ich Helena_Base.eep nicht flashen. Ist das ein Problem?
Die Lampe scheint bis auf den Beschleunigungssensor zu funktionieren.

Reisi, 2022-08-31:
Das ist kein Problem, das File ist sowieso "leer". Die Software kommt mit einem leeren EEPROM klar und nimmt dann Defaultwerte.

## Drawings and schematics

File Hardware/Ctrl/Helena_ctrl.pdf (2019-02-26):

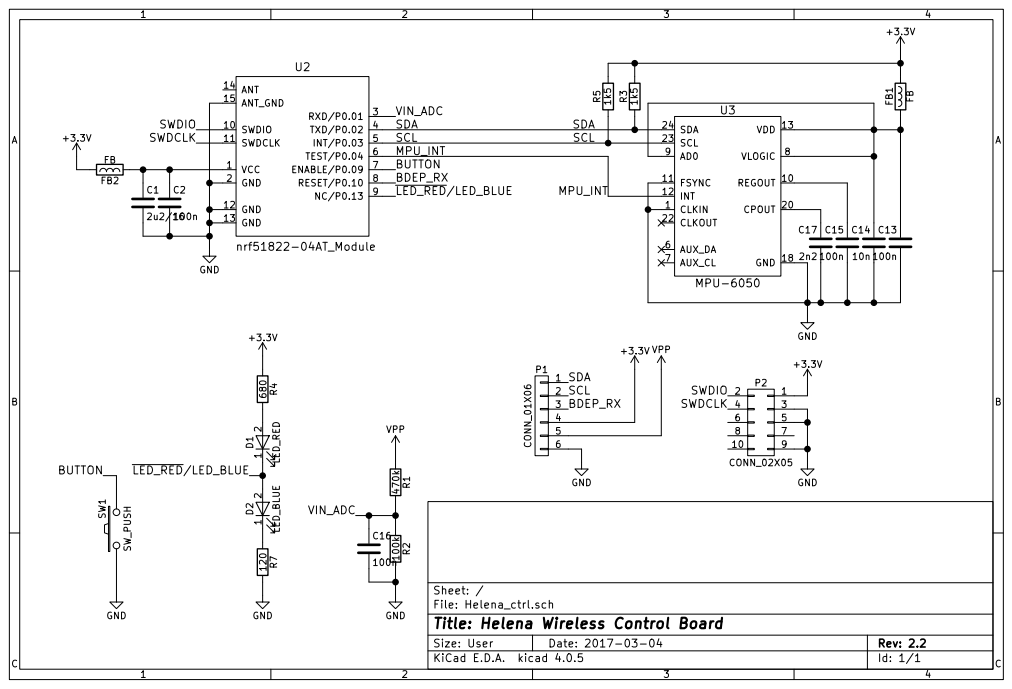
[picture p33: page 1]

SCL | SCL
MPU_INT

Id: 1/1 Title: Helena Wireless Control Board

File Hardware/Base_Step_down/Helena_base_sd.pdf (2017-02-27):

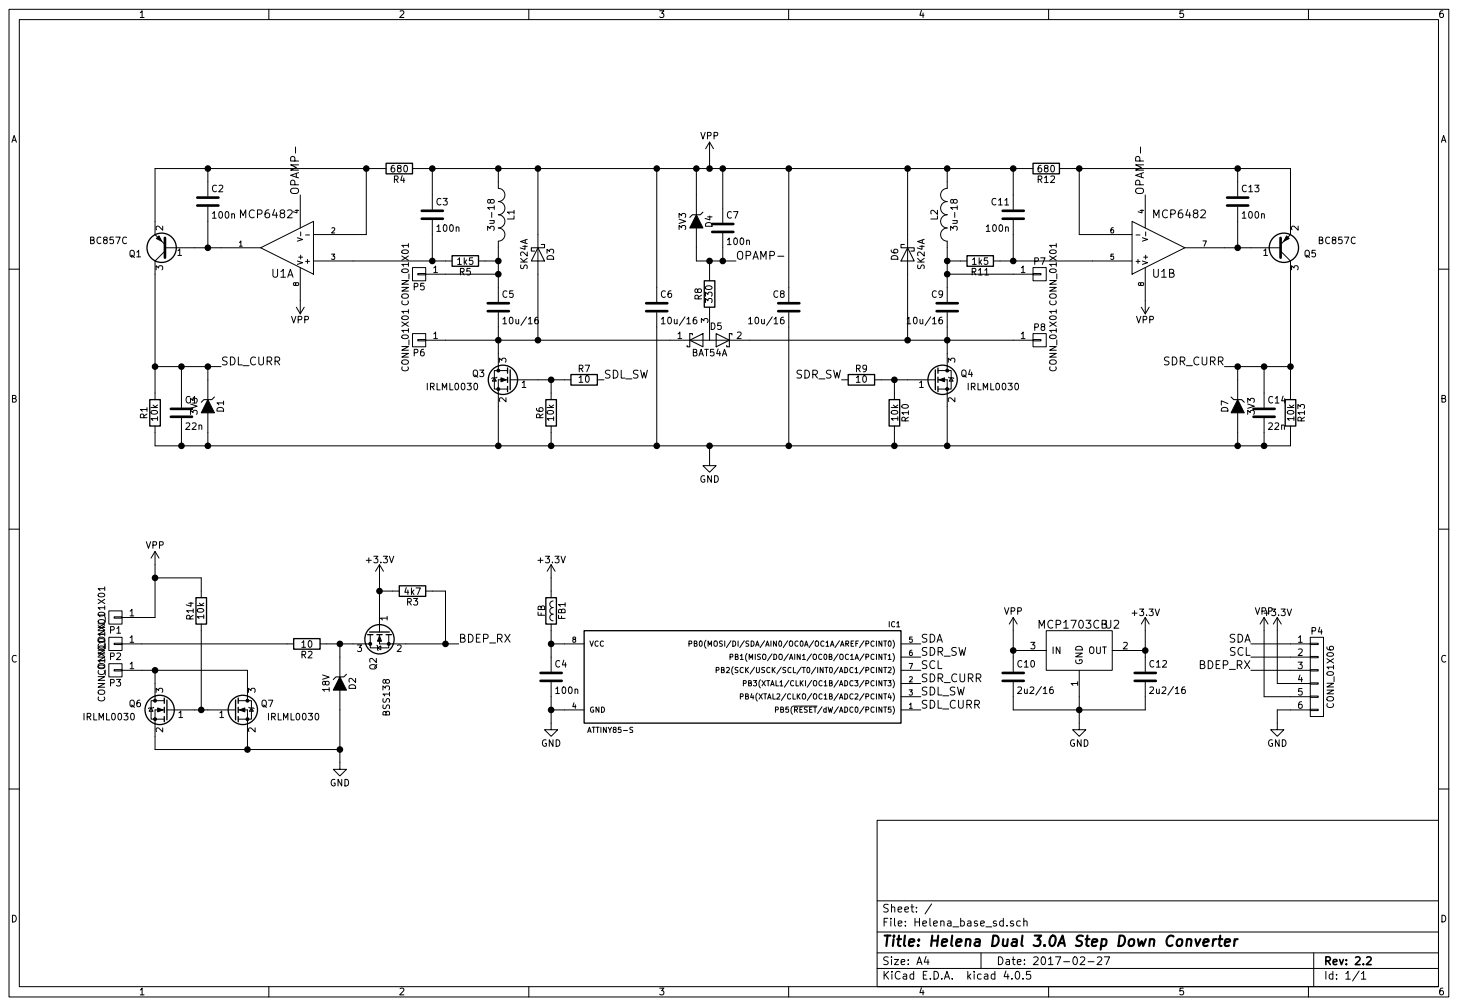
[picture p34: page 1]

Id: 1/1 Title: Helena Dual 3.0A Step Down Converter

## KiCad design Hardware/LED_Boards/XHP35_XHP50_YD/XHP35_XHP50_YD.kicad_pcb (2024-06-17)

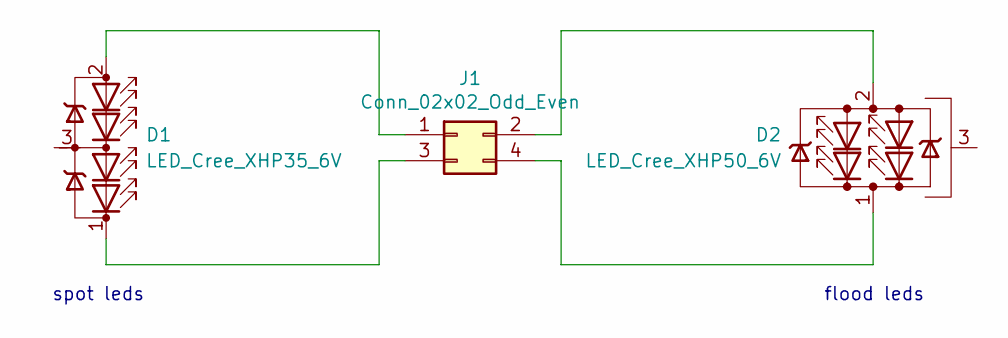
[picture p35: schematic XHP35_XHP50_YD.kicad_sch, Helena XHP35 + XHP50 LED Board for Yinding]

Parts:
D1: LED_Cree_XHP35_6V; LED_Cree-XHP50_12V
D2: LED_Cree_XHP50_6V; LED_Cree-XHP50_6V
J1: Conn_02x02_Odd_Even; PinHeader_2x02_P2.00mm_Vertical_SMD

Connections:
unnamed: D1.2 (A), J1.1
unnamed: D1.1 (K), J1.3
unnamed: D2.2 (A), J1.2
unnamed: D2.1 (K), J1.4

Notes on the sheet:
flood leds
spot leds

Board: 2 copper layers, 3 parts (0 on the bottom side), 4 nets, no tracks yet.

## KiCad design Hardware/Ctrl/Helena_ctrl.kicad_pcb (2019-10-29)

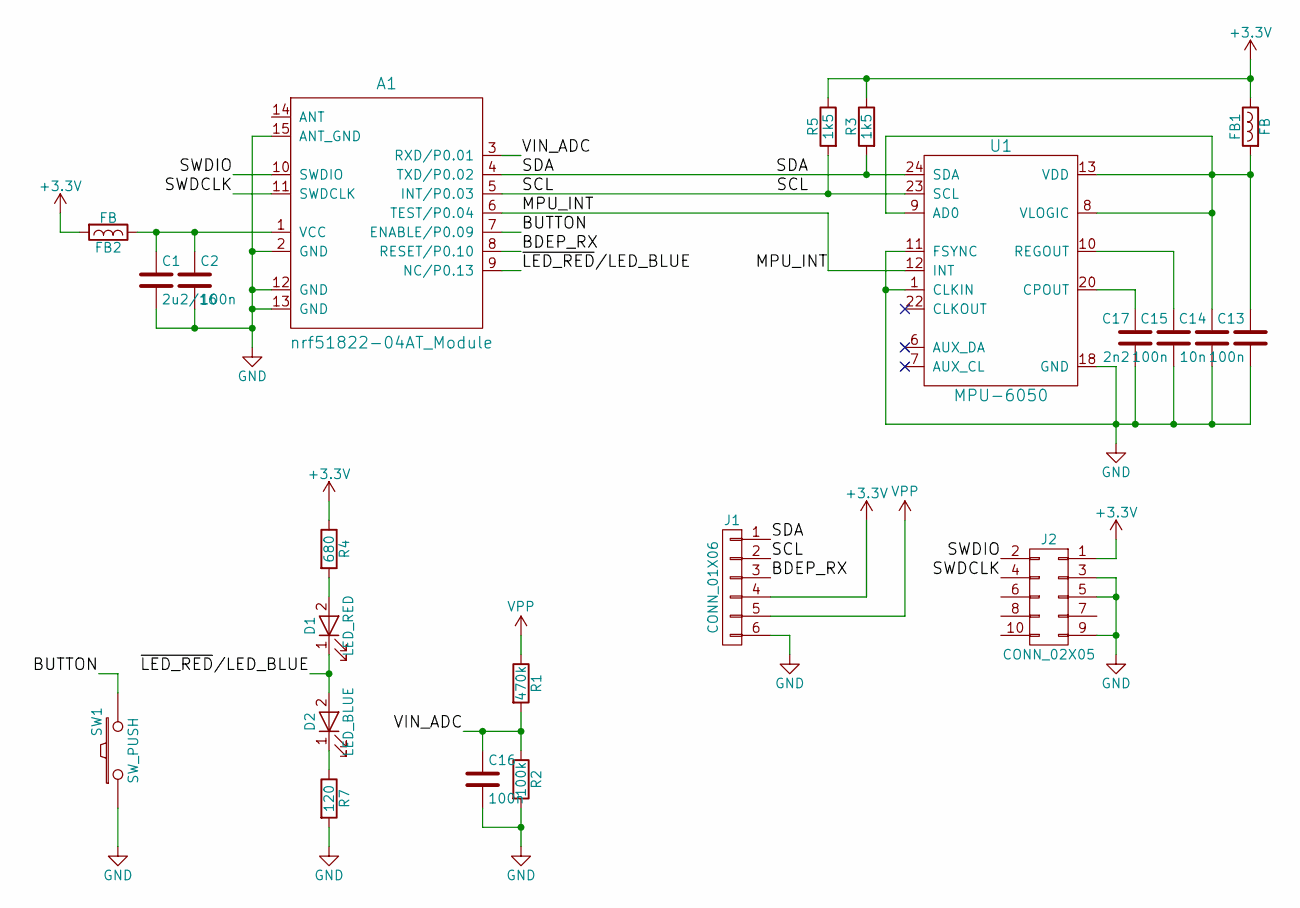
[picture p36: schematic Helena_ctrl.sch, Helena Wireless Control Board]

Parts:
A1: nrf51822-04AT_Module; WT51822-S4AT
C1: 2u2/16; C_0603_1608Metric
C2, C13, C15, C16: 100n; C_0603_1608Metric
C14: 10n; C_0603_1608Metric
C17: 2n2; C_0603_1608Metric
D1: LED_RED; D_0603_1608Metric
D2: LED_BLUE; D_0603_1608Metric
FB1, FB2: FB; L_0603_1608Metric
J1: CONN_01X06; PinHeader_1x06_P2.00mm_Vertical
J2: CONN_02X05; PinHeader_2x05_P1.27mm_Vertical
R1: 470k; R_0603_1608Metric
R2: 100k; R_0603_1608Metric
R3, R5: 1k5; R_0603_1608Metric
R4: 680; R_0603_1608Metric
R7: 120; R_0603_1608Metric
SW1: SW_PUSH; JTP-1138EM
U1: MPU-6050; QFN-24_4x4mm_Pitch0.5mm

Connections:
+3V3: FB1.1, FB2.2, J1.4, J2.1, R3.1, R4.1, R5.1
/BDEP_RX: A1.8 (RESET/P0.10), J1.3
/BUTTON: A1.7 (ENABLE/P0.09), SW1.2
/MPU_INT: A1.6 (TEST/P0.04), U1.12 (INT)
/SCL: A1.5 (INT/P0.03), J1.2, R5.2, U1.23 (SCL)
/SDA: A1.4 (TXD/P0.02), J1.1, R3.2, U1.24 (SDA)
/SWDCLK: A1.11 (SWDCLK), J2.4
/SWDIO: A1.10 (SWDIO), J2.2
/VIN_ADC: A1.3 (RXD/P0.01), C16.1, R1.2, R2.1
/~LED_RED~/LED_BLUE: A1.9 (NC/P0.13), D1.1 (K), D2.2 (A)
GND: A1.2 (GND), A1.12 (GND), A1.13 (GND), A1.15 (ANT_GND), C1.2, C2.2, C13.2, C14.2, C15.2, C16.2, C17.2, J1.6, J2.3, J2.5, J2.9, R2.2, R7.2, SW1.1, U1.1 (CLKIN), U1.11 (FSYNC), U1.18 (GND)
unnamed: A1.1 (VCC), C1.1, C2.1, FB2.1
unnamed: C13.1, C14.1, FB1.2, U1.8 (VLOGIC), U1.9 (AD0), U1.13 (VDD)
unnamed: C15.1, U1.10 (REGOUT)
unnamed: C17.1, U1.20 (CPOUT)
unnamed: D1.2 (A), R4.2
unnamed: D2.1 (K), R7.1
VPP: J1.5, R1.1

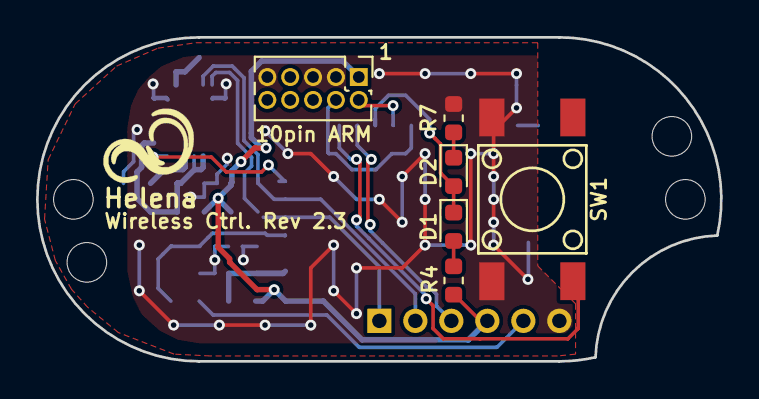
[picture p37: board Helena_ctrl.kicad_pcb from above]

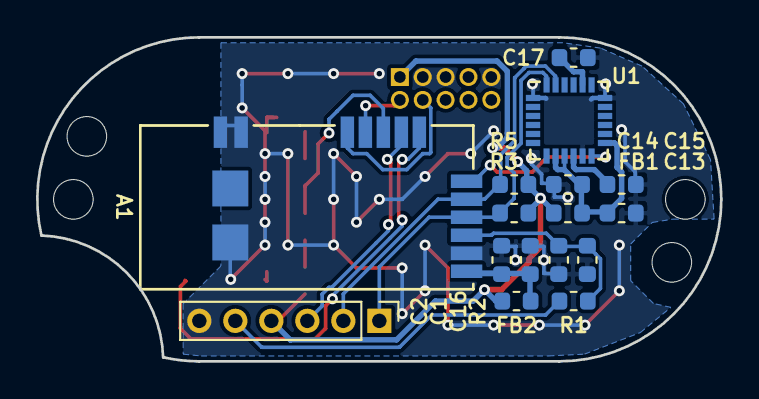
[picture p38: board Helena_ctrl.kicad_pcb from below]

Board: 2 copper layers, 38.0 x 18.0 mm, 22 parts (16 on the bottom side), 18 nets.

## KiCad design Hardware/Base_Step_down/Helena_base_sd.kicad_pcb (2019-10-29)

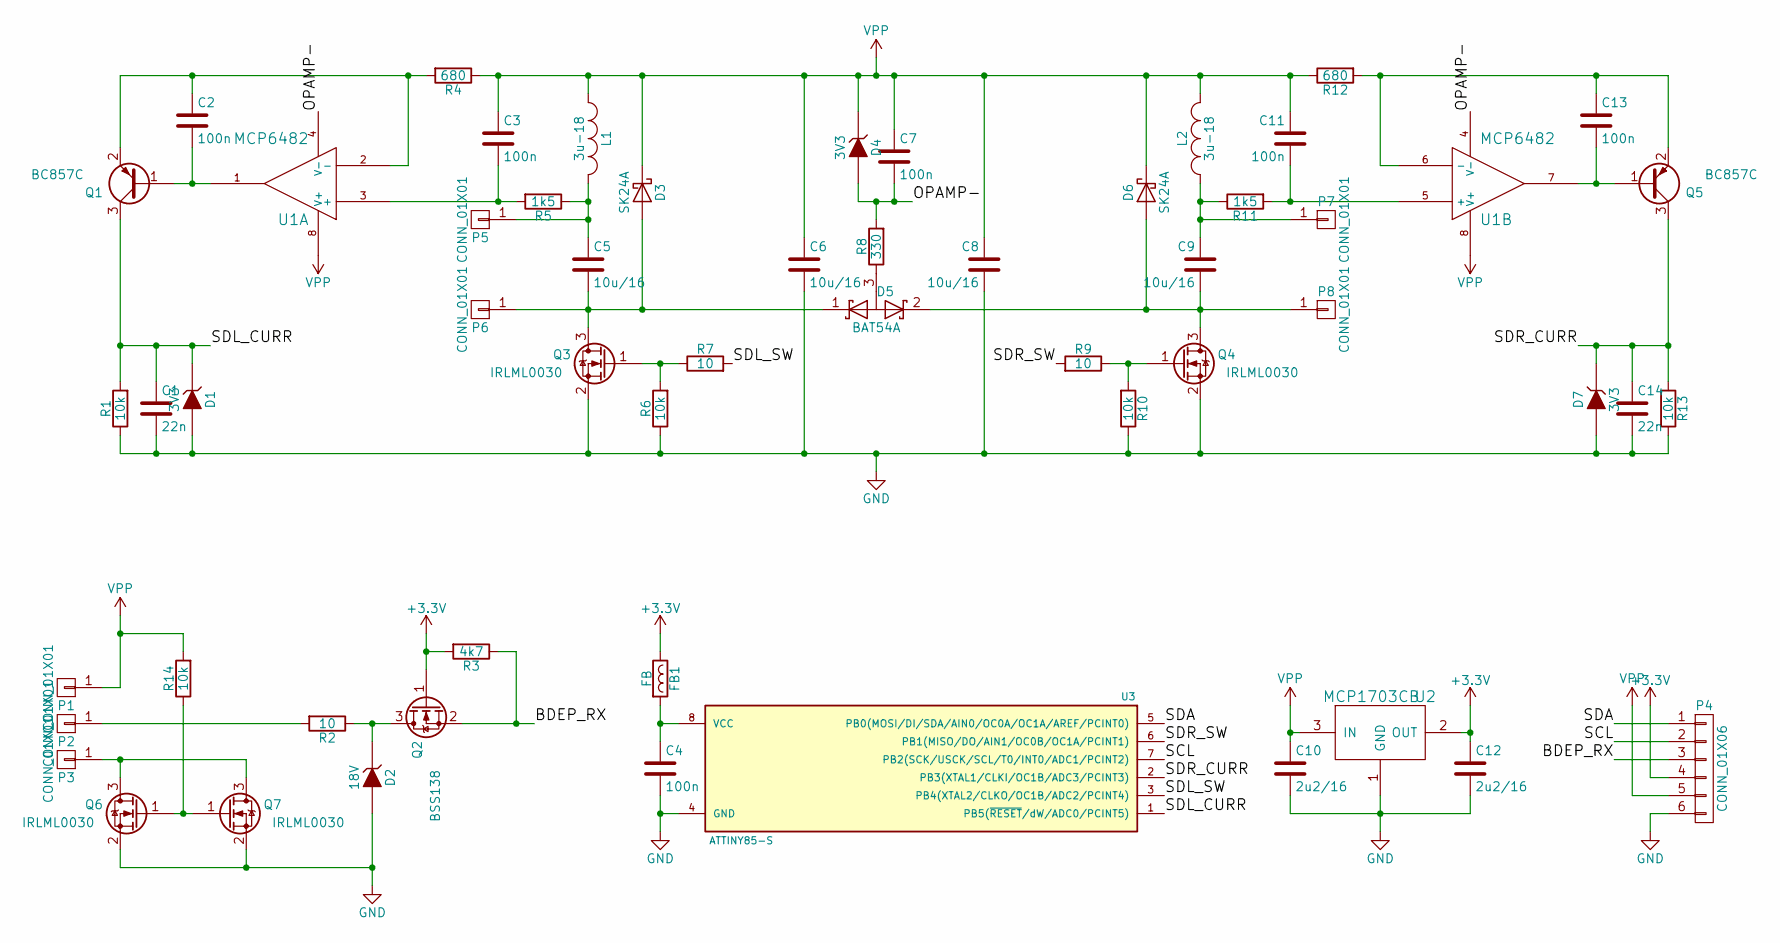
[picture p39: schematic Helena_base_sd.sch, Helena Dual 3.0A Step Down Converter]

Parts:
C1, C14: 22n; C_0603_1608Metric
C2, C3, C4, C7, C11, C13: 100n; C_0603_1608Metric
C5, C9: 10u/16; C_0805_2012Metric
C6, C8: 10u/16; C_1206_3216Metric
C10, C12: 2u2/16; C_0603_1608Metric
D1, D4, D7: 3V3; SOT-23
D2: 18V; SOT-23
D3, D6: SK24A; D_SMA
D5: BAT54A; SOT-23
FB1: FB; L_0603_1608Metric
L1, L2: 3u-18; Choke_SMD_Fastron_242418_FPS
P1, P2, P3: CONN_01X01; 1,5x3mm_SMD
P4: CONN_01X06; Pin_Header_Straight_1x06_2.00_Pitch
P5, P6, P7, P8: CONN_01X01; MILLMAX_5660
Q1, Q5: BC857C; SOT-23
Q2: BSS138; SOT-23
Q3, Q4, Q6, Q7: IRLML0030; SOT-23
R1, R6, R10, R13, R14: 10k; R_0603_1608Metric
R2, R7, R9: 10; R_0603_1608Metric
R3: 4k7; R_0603_1608Metric
R4, R12: 680; R_0603_1608Metric
R5, R11: 1k5; R_0603_1608Metric
R8: 330; R_0603_1608Metric
U1: MCP6482; MSOP-8_3x3mm_P0.65mm
U2: MCP1703CB; SOT-23W
U3: ATTINY85-S; SOIC-8_5.23x5.23mm_P1.27mm

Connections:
+3V3: C12.1, FB1.1, P4.4, Q2.1 (G), R3.2, U2.2 (OUT)
/BDEP_RX: P4.3, Q2.2 (S), R3.1
/OPAMP-: C7.2, D4.1 (A), R8.2, U1.4 (V-)
/SCL: P4.2, U3.7 (PB2(SCK/USCK/SCL/T0/INT0/ADC1/PCINT2))
/SDA: P4.1, U3.5 (PB0(MOSI/DI/SDA/AIN0/OC0A/OC1A/AREF/PCI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)
/SDL_CURR: C1.1, D1.3 (K), Q1.3 (C), R1.2, U3.1 (PB5(~RESET~/dW/ADC0/PCINT5))
/SDL_SW: R7.2, U3.3 (PB4(XTAL2/CLKO/OC1B/ADC2/PCINT4))
/SDR_CURR: C14.1, D7.3 (K), Q5.3 (C), R13.2, U3.2 (PB3(XTAL1/CLKI/OC1B/ADC3/PCINT3))
/SDR_SW: R9.2, U3.6 (PB1(MISO/DO/AIN1/OC0B/OC1A/PCINT1))
GND: C1.2, C4.2, C6.2, C8.2, C10.2, C12.2, C14.2, D1.1 (A), D2.1 (A), D7.1 (A), P4.6, Q3.2 (S), Q4.2 (S), Q6.2 (S), Q7.2 (S), R1.1, R6.1, R10.1, R13.1, U2.1 (GND), U3.4 (GND)
unnamed: C2.1, Q1.2 (E), R4.2, U1.2 (-)
unnamed: C2.2, Q1.1 (B), U1.1
unnamed: C3.2, R5.2, U1.3 (+)
unnamed: C4.1, FB1.2, U3.8 (VCC)
unnamed: C5.1, L1.2, P5.1, R5.1
unnamed: C5.2, D3.2 (A), D5.1 (K), P6.1, Q3.3 (D)
unnamed: C9.1, L2.2, P7.1, R11.1
unnamed: C9.2, D5.2 (K), D6.2 (A), P8.1, Q4.3 (D)
unnamed: C11.2, R11.2, U1.5 (+)
unnamed: C13.1, Q5.2 (E), R12.2, U1.6 (-)
unnamed: C13.2, Q5.1 (B), U1.7
unnamed: D2.3 (K), Q2.3 (D), R2.1
unnamed: D5.3 (A), R8.1
unnamed: P2.1, R2.2
unnamed: P3.1, Q6.3 (D), Q7.3 (D)
unnamed: Q3.1 (G), R6.2, R7.1
unnamed: Q4.1 (G), R9.1, R10.2
unnamed: Q6.1 (G), Q7.1 (G), R14.1
VPP: C3.1, C6.1, C7.1, C8.1, C10.1, C11.1, D3.1 (K), D4.3 (K), D6.1 (K), L1.1, L2.1, P1.1, P4.5, R4.1, R12.1, R14.2, U1.8 (V+), U2.3 (IN)

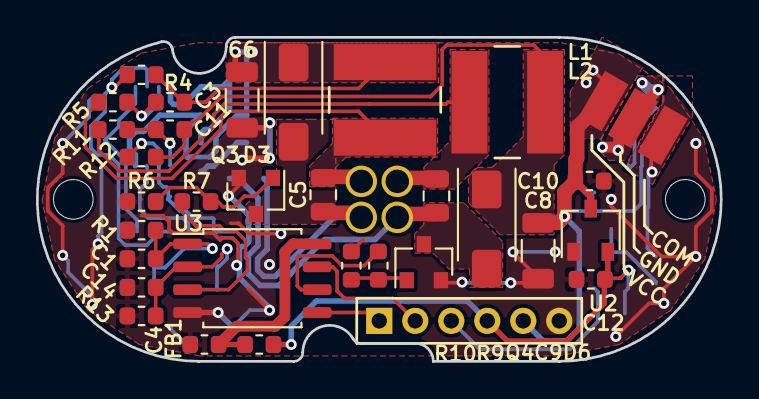
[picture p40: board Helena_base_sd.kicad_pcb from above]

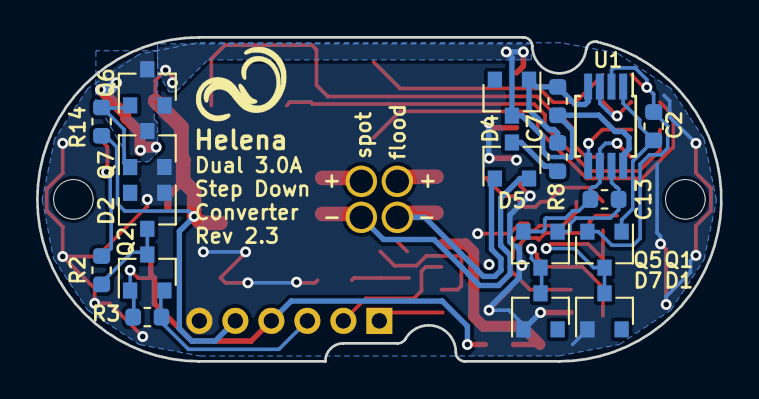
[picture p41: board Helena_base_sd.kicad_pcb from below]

Board: 2 copper layers, 38.0 x 18.0 mm, 56 parts (18 on the bottom side), 29 nets.

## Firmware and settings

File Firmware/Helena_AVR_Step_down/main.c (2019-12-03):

/**
  ******************************************************************************
  * @file    main.c
  * @author  Thomas Reisnecker
  * @brief   main module for 2 Channel i2c SMPS Module
  ******************************************************************************
  */

/* Includes ------------------------------------------------------------------*/
#include <string.h>
#include <avr/io.h>
#include <stdint.h>
#include <avr/eeprom.h>
#include <avr/sleep.h>
#include <avr/power.h>
#include <avr/wdt.h>
#include <avr/interrupt.h>
#include <util/atomic.h>
#include "usiTwiSlave.h"
#include "adc.h"
#include "main.h"
#include "smps.h"

/* External variables --------------------------------------------------------*/

/* Private typedef -----------------------------------------------------------*/
typedef struct {
    uint8_t AdcConfig:4;
    uint8_t Sleep:1;
    uint8_t TargetStepDownLeft;
    uint8_t TargetStepDownRight;
    uint16_t CurrentStepDownLeft;
    uint8_t StatusStepDownLeft;
    uint16_t CurrentStepDownRight;
    uint8_t StatusStepDownRight;
    uint16_t Temperature;
    adc_compensation_t adcComp;
    uint8_t adcXor;
} main_data_t;

/* Private macros ------------------------------------------------------------*/

/* Private defines -----------------------------------------------------------*/
#ifndef NULL
#define NULL 0
#endif

//#define CALIBRATION     // if this flag is enabled, both drivers are set to
                        // output 0.75A, and the temperature value is stored
                        // to last eeprom address approximately every 5 sec
#ifdef CALIBRATION
#define TEMPSAFECNT     (5*250000/(3*13))
#define TEMPSAFEADDR    (uint16_t*)510
#endif

/* Private variables ---------------------------------------------------------*/
static main_data_t main_Data;

/* Private functions ---------------------------------------------------------*/
static uint8_t calcXor(adc_compensation_t const* pComp)
{
    uint8_t xor = 0;

    xor = (uint8_t)(pComp->TemperatureOffset >> 8);
    xor ^= pComp->TemperatureOffset & 0x00FF;
    xor ^= pComp->CurrentLeftGain;
    xor ^= pComp->CurrentRightGain;

    return xor;
}

static void main_Init() {
    MCUSR &= ~(1<<WDRF);
    wdt_disable();
    ACSR |= (1<<ACD);
    power_timer0_disable();
    main_Data.Sleep = 1;
    main_Data.AdcConfig = WDTO_1S;

    int16_t tOffset = eeprom_read_word(TEMPOFFS);
    uint8_t gainLeft = eeprom_read_byte(LEFTGAIN);
    uint8_t gainRight = eeprom_read_byte(RIGHTGAIN);

    if (tOffset == 0xFFFF && gainLeft == 0xFF && gainRight == 0xFF)
    {
        adc_compensation_t def = ADC_COMPENSATION_DEFAULTS;
        main_Data.adcComp = def;
    }
    else
    {
        main_Data.adcComp.TemperatureOffset = tOffset;
        main_Data.adcComp.CurrentLeftGain = gainLeft;
        main_Data.adcComp.CurrentRightGain = gainRight;
    }
    main_Data.adcXor = calcXor(&main_Data.adcComp);

    adc_SetCompensation(&main_Data.adcComp);

    rxbuffer[0] = (main_Data.Sleep<<4) | main_Data.AdcConfig;
    rxbuffer[11] = main_Data.adcComp.TemperatureOffset >> 8;
    rxbuffer[12] = main_Data.adcComp.TemperatureOffset & 0x00FF;
    rxbuffer[13] = main_Data.adcComp.CurrentLeftGain;
    rxbuffer[14] = main_Data.adcComp.CurrentRightGain;
    rxbuffer[15] = main_Data.adcXor;

    txbuffer[0] = (main_Data.Sleep<<4) | main_Data.AdcConfig;
}

int main(void) {
    usiTwiSlaveInit(0x3A<<1);
    adc_Init();
    main_Init();
    smps_Init();
    sei();

    while (1) {

#ifdef CALIBRATION
        main_Data.Sleep = 0;
        main_Data.TargetStepDownLeft = 64;
        main_Data.TargetStepDownRight = 64;
#else
        /**
         * receiving twi data handling
         */
        main_Data.AdcConfig = rxbuffer[0] & 0x0F;
        if (rxbuffer[0] & (1<<4))
            main_Data.Sleep = 1;
        else
            main_Data.Sleep = 0;
        main_Data.TargetStepDownLeft = rxbuffer[1];
        main_Data.TargetStepDownRight = rxbuffer[2];
        adc_compensation_t rcvdComp;
        rcvdComp.TemperatureOffset = (int16_t)(((uint16_t)rxbuffer[11] << 8) | rxbuffer[12]);
        rcvdComp.CurrentLeftGain = rxbuffer[13];
        rcvdComp.CurrentRightGain = rxbuffer[14];
        uint8_t xor = rxbuffer[15];
        if (calcXor(&rcvdComp) == xor)
        {
            if (memcmp(&rcvdComp, &main_Data.adcComp, sizeof(adc_compensation_t)) != 0)
            {
                main_Data.adcComp = rcvdComp;
                main_Data.adcXor = xor;
                eeprom_update_word(TEMPOFFS, rcvdComp.TemperatureOffset);
                eeprom_update_byte(LEFTGAIN, rcvdComp.CurrentLeftGain);
                eeprom_update_byte(RIGHTGAIN, rcvdComp.CurrentRightGain);
                adc_SetCompensation(&rcvdComp);
            }
        }

        /**
         * transmitting twi data handling
         */
        ATOMIC_BLOCK(ATOMIC_FORCEON) {txbuffer[0] = (main_Data.Sleep<<4) | main_Data.AdcConfig;}
        txbuffer[1] = main_Data.TargetStepDownLeft;
        txbuffer[2] = main_Data.TargetStepDownRight;
        if (!(USICR & (1<<USIOIE))) {
            ATOMIC_BLOCK(ATOMIC_FORCEON) {
                txbuffer[3] = (main_Data.StatusStepDownLeft<<4) | ((main_Data.CurrentStepDownLeft & 0x0FFF)>>8);
                txbuffer[4] = main_Data.CurrentStepDownLeft & 0x00FF;
            }
            ATOMIC_BLOCK(ATOMIC_FORCEON) {
                txbuffer[5] = (main_Data.StatusStepDownRight<<4) | ((main_Data.CurrentStepDownRight & 0x0FFF)>>8);
                txbuffer[6] = main_Data.CurrentStepDownRight & 0x00FF;
            }
            ATOMIC_BLOCK(ATOMIC_FORCEON) {
                txbuffer[7] = (main_Data.Temperature & 0x0FFF)>>8;
                txbuffer[8] = main_Data.Temperature & 0x00FF;
            }
            txbuffer[9] = smps_GetDutyCycle(smps_STEPDOWNLEFT);
            txbuffer[10] = smps_GetDutyCycle(smps_STEPDOWNRIGHT);
            ATOMIC_BLOCK(ATOMIC_FORCEON) {
                txbuffer[11] = main_Data.adcComp.TemperatureOffset >> 8;
                txbuffer[12] = main_Data.adcComp.TemperatureOffset & 0x00FF;
            }
            txbuffer[13] = main_Data.adcComp.CurrentLeftGain;
            txbuffer[14] = main_Data.adcComp.CurrentRightGain;
            txbuffer[15] = main_Data.adcXor;
        }
        main_flag &= ~(1<<USIRXDONE);
#endif // CALIBRATION

        /**
         * Sleep mode checking, turn on or off watchdog with desired repetition
         * rate to trigger analog conversions
         */
        if (main_Data.Sleep == 0) {
            uint8_t i = WDTCR & 0x07;
            if (WDTCR & (1<<WDP3))
                i |= (1<<3);
            if (!(WDTCR & (1<<WDIE)) || (main_Data.AdcConfig != i)) {
                wdt_enable(main_Data.AdcConfig);
                WDTCR |= (1<<WDIE);
            }
        }
        else {
            if (WDTCR & (1<<WDIE)) {
                MCUSR &= ~(1<<WDRF);
                wdt_disable();
            }
        }
        if (main_flag & (1<<WATCHDOG)) {
            main_flag &= ~(1<<WATCHDOG);
            if (adc_Off())
                adc_StartCycle();
        }

        /**
         * Enable smps module if necessary and configure ADC in continuous mode
         */
        if ((main_Data.Sleep == 0) && (main_Data.TargetStepDownLeft || main_Data.TargetStepDownRight) && smps_Off()) {
            smps_Enable();
            adc_SetMode(ADC_MODE_CONTINUOUS);
            if (adc_Off())
                adc_StartCycle();
        }

        /**
         * Disable smps module if necessary and configure ADC in singleshot mode
         */
        if (((main_Data.Sleep != 0) || (!main_Data.TargetStepDownLeft && !main_Data.TargetStepDownRight)) && !smps_Off()) {
            smps_Disable();
            adc_SetMode(ADC_MODE_SINGLESHOT);
        }

        /**
         * compensate analog values and call regulator if necessary
         */
        if (main_flag & (1<<SAMPLETEMPERATURE)) {
            main_flag &= ~(1<<SAMPLETEMPERATURE);
            main_Data.Temperature = adc_GetCompensated(ADC_DATA_TEMPERATURE);
#ifdef CALIBRATION
            static uint16_t cnt = TEMPSAFECNT;
            if (--cnt == 0)
            {
                cnt = TEMPSAFECNT;
                eeprom_update_word(TEMPSAFEADDR, main_Data.Temperature);
            }
#endif // CALIBRATION
        }
        if (main_flag & (1<<SAMPLESTEPDOWNLEFT)) {
            main_flag &= ~(1<<SAMPLESTEPDOWNLEFT);
            main_Data.CurrentStepDownLeft = adc_GetCompensated(ADC_DATA_CURRENTLEFT);
            if (!smps_Off())
                main_Data.StatusStepDownLeft = smps_Regulator(smps_STEPDOWNLEFT, (uint16_t)main_Data.TargetStepDownLeft<<4, main_Data.CurrentStepDownLeft);
        }
        if (main_flag & (1<<SAMPLESTEPDOWNRIGHT)) {
            main_flag &= ~(1<<SAMPLESTEPDOWNRIGHT);
            main_Data.CurrentStepDownRight = adc_GetCompensated(ADC_DATA_CURRENTRIGHT);
            if (!smps_Off())
                main_Data.StatusStepDownRight = smps_Regulator(smps_STEPDOWNRIGHT, (uint16_t)main_Data.TargetStepDownRight<<4, main_Data.CurrentStepDownRight);
        }

        /*main_pComMessage = com_Check();
        if (main_pComMessage != NULL) {
            if ((main_pComMessage->Identifier == 0x00) && (main_pComMessage->Control == 0x03)) {
                if (main_pComMessage->Data[0] & (1<<4))
                    main_Data.Sleep = 1;
                else
                    main_Data.Sleep = 0;
                main_Data.AdcConfig = main_pComMessage->Data[0] & 0x0F;
                main_Data.TargetStepDownLeft = main_pComMessage->Data[1];
                main_Data.TargetStepDownRight = main_pComMessage->Data[2];
            }
            else if ((main_pComMessage->Identifier == 0x01) && (main_pComMessage->Control == 0xF0)) {
                com_MessageStruct Message;
                Message.Identifier = 0x01;
                Message.Control = 0x09;
                Message.Data[0] = main_Data.AdcConfig | (main_Data.Sleep<<4);
                Message.Data[1] = main_Data.TargetStepDownLeft;
                Message.Data[2] = main_Data.TargetStepDownRight;
                Message.Data[3] = (main_Data.StatusStepDownLeft<<4) | ((main_Data.CurrentStepDownLeft & 0x0FFF)>>8);
                Message.Data[4] = main_Data.CurrentStepDownLeft & 0x00FF;
                Message.Data[5] = (main_Data.StatusStepDownRight<<4) | ((main_Data.CurrentStepDownRight & 0x0FFF)>>8);
                Message.Data[6] = main_Data.CurrentStepDownRight & 0x00FF;
                Message.Data[7] = OCR1A;//main_Data.Temperature>>8;
                Message.Data[8] = OCR1B;//main_Data.Temperature & 0x00FF;
                com_Put(&Message);
            }
        }*/

        if (usiCheckForStop() != 0)
            main_flag |= (1<<USIRXDONE);

        /**
         * sleep mode handling (don't use sleep mode if ADC is running,
         * otherwise unwanted conversions may be triggered
         */
        if (adc_Off() && !main_flag && !(USICR & (1<<USIOIE))) {
            cli();
            sleep_enable();
            if (((~PRR) & ((1<<PRTIM0)|(1<<PRTIM1)|(1<<PRADC))) )
                set_sleep_mode(SLEEP_MODE_IDLE);
            else {
                set_sleep_mode(SLEEP_MODE_PWR_DOWN);
                sleep_bod_disable();
            }
            sei();
            sleep_cpu();
            sleep_disable();
        }
    }
}

ISR(WDT_vect) {
    main_flag |= (1<<WATCHDOG);
    WDTCR |= (1<<WDIE);
}

/* Public functions ----------------------------------------------------------*/

/**END OF FILE*****************************************************************/

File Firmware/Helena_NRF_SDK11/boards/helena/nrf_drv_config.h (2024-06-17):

/* Copyright (c) 2015 Nordic Semiconductor. All Rights Reserved.
 *
 * The information contained herein is property of Nordic Semiconductor ASA.
 * Terms and conditions of usage are described in detail in NORDIC
 * SEMICONDUCTOR STANDARD SOFTWARE LICENSE AGREEMENT.
 *
 * Licensees are granted free, non-transferable use of the information. NO
 * WARRANTY of ANY KIND is provided. This heading must NOT be removed from
 * the file.
 *
 */

#ifndef NRF_DRV_CONFIG_H
#define NRF_DRV_CONFIG_H

/**
 * Provide a non-zero value here in applications that need to use several
 * peripherals with the same ID that are sharing certain resources
 * (for example, SPI0 and TWI0). Obviously, such peripherals cannot be used
 * simultaneously. Therefore, this definition allows to initialize the driver
 * for another peripheral from a given group only after the previously used one
 * is uninitialized. Normally, this is not possible, because interrupt handlers
 * are implemented in individual drivers.
 * This functionality requires a more complicated interrupt handling and driver
 * initialization, hence it is not always desirable to use it.
 */
#define PERIPHERAL_RESOURCE_SHARING_ENABLED  0

/* CLOCK */
#define CLOCK_ENABLED 0

#if (CLOCK_ENABLED == 1)
#define CLOCK_CONFIG_XTAL_FREQ          NRF_CLOCK_XTALFREQ_Default
#define CLOCK_CONFIG_LF_SRC             NRF_CLOCK_LFCLK_Xtal
#define CLOCK_CONFIG_IRQ_PRIORITY       APP_IRQ_PRIORITY_LOW
#endif

/* GPIOTE */
#define GPIOTE_ENABLED 1

#if (GPIOTE_ENABLED == 1)
#define GPIOTE_CONFIG_USE_SWI_EGU false
#define GPIOTE_CONFIG_IRQ_PRIORITY APP_IRQ_PRIORITY_LOW
#define GPIOTE_CONFIG_NUM_OF_LOW_POWER_EVENTS 3
#endif

/* TIMER */
#define TIMER0_ENABLED 0

#if (TIMER0_ENABLED == 1)
#define TIMER0_CONFIG_FREQUENCY    NRF_TIMER_FREQ_16MHz
#define TIMER0_CONFIG_MODE         TIMER_MODE_MODE_Timer
#define TIMER0_CONFIG_BIT_WIDTH    TIMER_BITMODE_BITMODE_32Bit
#define TIMER0_CONFIG_IRQ_PRIORITY APP_IRQ_PRIORITY_LOW

#define TIMER0_INSTANCE_INDEX      0
#endif

#define TIMER1_ENABLED 1

#if (TIMER1_ENABLED == 1)
#define TIMER1_CONFIG_FREQUENCY    NRF_TIMER_FREQ_16MHz
#define TIMER1_CONFIG_MODE         TIMER_MODE_MODE_Timer
#define TIMER1_CONFIG_BIT_WIDTH    TIMER_BITMODE_BITMODE_16Bit
#define TIMER1_CONFIG_IRQ_PRIORITY APP_IRQ_PRIORITY_LOW

#define TIMER1_INSTANCE_INDEX      (TIMER0_ENABLED)
#endif

#define TIMER2_ENABLED 0

#if (TIMER2_ENABLED == 1)
#define TIMER2_CONFIG_FREQUENCY    NRF_TIMER_FREQ_16MHz
#define TIMER2_CONFIG_MODE         TIMER_MODE_MODE_Timer
#define TIMER2_CONFIG_BIT_WIDTH    TIMER_BITMODE_BITMODE_16Bit
#define TIMER2_CONFIG_IRQ_PRIORITY APP_IRQ_PRIORITY_LOW

#define TIMER2_INSTANCE_INDEX      (TIMER1_ENABLED+TIMER0_ENABLED)
#endif

#define TIMER3_ENABLED 0

#if (TIMER3_ENABLED == 1)
#define TIMER3_CONFIG_FREQUENCY    NRF_TIMER_FREQ_16MHz
#define TIMER3_CONFIG_MODE         TIMER_MODE_MODE_Timer
#define TIMER3_CONFIG_BIT_WIDTH    TIMER_BITMODE_BITMODE_16Bit
#define TIMER3_CONFIG_IRQ_PRIORITY APP_IRQ_PRIORITY_LOW

#define TIMER3_INSTANCE_INDEX      (TIMER2_ENABLED+TIMER1_ENABLED+TIMER0_ENABLED)
#endif

#define TIMER4_ENABLED 0

#if (TIMER4_ENABLED == 1)
#define TIMER4_CONFIG_FREQUENCY    NRF_TIMER_FREQ_16MHz
#define TIMER4_CONFIG_MODE         TIMER_MODE_MODE_Timer
#define TIMER4_CONFIG_BIT_WIDTH    TIMER_BITMODE_BITMODE_16Bit
#define TIMER4_CONFIG_IRQ_PRIORITY APP_IRQ_PRIORITY_LOW

#define TIMER4_INSTANCE_INDEX      (TIMER3_ENABLED+TIMER2_ENABLED+TIMER1_ENABLED+TIMER0_ENABLED)
#endif


#define TIMER_COUNT (TIMER0_ENABLED + TIMER1_ENABLED + TIMER2_ENABLED + TIMER3_ENABLED + TIMER4_ENABLED)

/* RTC */
#define RTC0_ENABLED 0

#if (RTC0_ENABLED == 1)
#define RTC0_CONFIG_FREQUENCY    32678
#define RTC0_CONFIG_IRQ_PRIORITY APP_IRQ_PRIORITY_LOW
#define RTC0_CONFIG_RELIABLE     false

#define RTC0_INSTANCE_INDEX      0
#endif

#define RTC1_ENABLED 0

#if (RTC1_ENABLED == 1)
#define RTC1_CONFIG_FREQUENCY    32768
#define RTC1_CONFIG_IRQ_PRIORITY APP_IRQ_PRIORITY_LOW
#define RTC1_CONFIG_RELIABLE     false

#define RTC1_INSTANCE_INDEX      (RTC0_ENABLED)
#endif

#define RTC2_ENABLED 0

#if (RTC2_ENABLED == 1)
#define RTC2_CONFIG_FREQUENCY    32768
#define RTC2_CONFIG_IRQ_PRIORITY APP_IRQ_PRIORITY_LOW
#define RTC2_CONFIG_RELIABLE     false

#define RTC2_INSTANCE_INDEX      (RTC0_ENABLED+RTC1_ENABLED)
#endif


#define RTC_COUNT                (RTC0_ENABLED+RTC1_ENABLED+RTC2_ENABLED)

#define NRF_MAXIMUM_LATENCY_US 2000

/* RNG */
#define RNG_ENABLED 0

#if (RNG_ENABLED == 1)
#define RNG_CONFIG_ERROR_CORRECTION true
#define RNG_CONFIG_POOL_SIZE        8
#define RNG_CONFIG_IRQ_PRIORITY     APP_IRQ_PRIORITY_LOW
#endif

/* PWM */

#define PWM0_ENABLED 0
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

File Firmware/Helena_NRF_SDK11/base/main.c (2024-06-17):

/**
  ******************************************************************************
  * @file    main.c
  * @author  Thomas Reisnecker
  * @brief   main module for Helena
  ******************************************************************************
  */

/* logger configuration ------------------------------------------------------*/
#define MAIN_LOG_ENABLED

#ifdef MAIN_LOG_ENABLED
#include "log.h"
#else
#define LOG_ERROR(...)
#define LOG_INFO(...)
#endif // MAIN_LOG_ENABLED

/* Includes ------------------------------------------------------------------*/
#include "main.h"
#include "debug.h"
#include "app_error.h"
#include "softdevice_handler.h"
#include "btle.h"
#include "link_management.h"
#include "mode_management.h"
#include "app_timer.h"
#include "hmi.h"
#include "string.h"
#include "board.h"
#include "com_message_handling.h"

/* Private defines -----------------------------------------------------------*/
#define APP_TIMER_PRESCALER     MAIN_TIMER_PRESCALER
#define APP_TIMER_OP_QUEUE_SIZE 2

#define IDLE_TIMEOUT            MAIN_TIMER_TICKS(180000)
#define IDLE_PERIOD             MAIN_TIMER_TICKS(10000)

/* Private typedef -----------------------------------------------------------*/
typedef enum
{
    MAINSTATE_OFF,      // device enters system off mode
    MAINSTATE_STANDBY,
    MAINSTATE_IDLE
} mState_t;

typedef enum
{
    FLOPSCR_NONE,   // no source
    FLOPSCR_HMI,    // flash operation request from hmi module
    /// TODO: why is there nothing from Helen Project Service?
} pendingFlashOpSource_t;

typedef struct
{
    volatile uint8_t pendingResponses;  // the number of responses to be expected
    pendingFlashOpSource_t source;
    uint32_t firstErrorCode;
    union
    {
        ds_reportHandler_t hmiResponse; // response handler for events related to the hmi module
    };
} pendingFlashOp_t;

/* Private macros ------------------------------------------------------------*/
#define ARRAY_SIZE(x)           (sizeof(x)/sizeof(x[0]))
#define SYSEVENT_CNT()          NRF_SECTION_VARS_COUNT(main_SysEventHandler_t, sys_events)
#define SYSEVENT_GET(cnt)       NRF_SECTION_VARS_GET(cnt, main_SysEventHandler_t, sys_events)

/* Private variables ---------------------------------------------------------*/
static mState_t mainState;
static uint32_t idleCounter;
APP_TIMER_DEF(idleTimer);
static pendingFlashOp_t pendingFlashOp;

/* Private read only variables -----------------------------------------------*/
/// TODO: this must be configured at compile time
static nrf_clock_lf_cfg_t const clockConfig =
{
    .source = NRF_CLOCK_LF_SRC_RC,
    .rc_ctiv = 16,
    .rc_temp_ctiv = 1
};

/* Private functions ---------------------------------------------------------*/
static void modeChanged(uint8_t newMode)
{
    //LOG_INFO("[main]: new mode %d", newMode);

    if (newMode == MM_MODE_OFF)
        newMode = mm_GetOffMode();
    ret_code_t errCode = brd_SetLightMode(newMode);
    if (errCode != NRF_SUCCESS)
    {
        LOG_ERROR("setting light mode error %d", errCode);
    }
}

static void sysEventDispatch(uint32_t sysEvt)
{
    for (uint_fast8_t i = 0; i < SYSEVENT_CNT(); i++)
    {
        main_SysEventHandler_t const* pHandler = SYSEVENT_GET(i);
        if (pHandler->pHandler != NULL)
            pHandler->pHandler(sysEvt);
    }
}

void idleTimerCallback(void * pContext)
{
    (void)pContext;

    if (idleCounter == 0 || (--idleCounter != 0))
        return;

    mainState = MAINSTATE_STANDBY;
    LOG_INFO("[main]: going to standby mode");

    ret_code_t errCode;
    errCode = lm_SetExposureMode(LM_EXP_LOW_POWER);
    if (errCode != NRF_SUCCESS)
    {
        LOG_ERROR("[main]: exposure mode set error %d", errCode);
    }

    errCode = brd_SetPowerMode(BRD_PM_STANDBY);
    if (errCode != NRF_SUCCESS)
    {
        LOG_ERROR("[main]: board power mode set error %d", errCode);
    }
}

static ret_code_t timerInit()
{
    APP_TIMER_INIT(APP_TIMER_PRESCALER, APP_TIMER_OP_QUEUE_SIZE, false);

    ret_code_t errCode = app_timer_create(&idleTimer, APP_TIMER_MODE_REPEATED, &idleTimerCallback);
    if (errCode != NRF_SUCCESS)
    {
        LOG_ERROR("[main]: idle timer create error %d", errCode);
        return errCode;
    }

    mainState = MAINSTATE_IDLE;
    idleCounter = IDLE_TIMEOUT / IDLE_PERIOD;
    errCode = app_timer_start(idleTimer, IDLE_PERIOD, NULL);
    if (errCode != NRF_SUCCESS)
    {
        LOG_ERROR("[main]: starting idle timer error %d", errCode);
    }

    return errCode;
}

static ret_code_t sdhInit(void)
{
    nrf_clock_lf_cfg_t clockConfig = CLOCK_CONFIG;

    SOFTDEVICE_HANDLER_INIT(&clockConfig, NULL);

    ret_code_t errCode = softdevice_sys_evt_handler_set(sysEventDispatch);
    if (errCode != NRF_SUCCESS)
    {
        LOG_ERROR("[main]: error %d on setting system event handler", errCode);
    }

    return errCode;
}

static void flashOpResultHandler(ret_code_t errCode)
{
    if (pendingFlashOp.pendingResponses == 0)
        return; // not expecting anything

    // preserve the first error code
    if (pendingFlashOp.firstErrorCode == NRF_SUCCESS)
        pendingFlashOp.firstErrorCode = errCode;

    if (--pendingFlashOp.pendingResponses == 0)
    {
        switch (pendingFlashOp.source)
        {
        case FLOPSCR_HMI:
            if (pendingFlashOp.hmiResponse != NULL)
                pendingFlashOp.hmiResponse(pendingFlashOp.firstErrorCode);
            break;

        default:
            break;
        }

        memset(&pendingFlashOp, 0, sizeof(pendingFlashOp));
    }
}

static bool isBlockZero(void const* pBlock, unsigned int size)
{
    unsigned char* pMem = (unsigned char*)pBlock;
    for (unsigned int i = 0; i < size; i++)
    {
        if(pMem[i] != 0)
            return false;
    }
    return true;
}
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

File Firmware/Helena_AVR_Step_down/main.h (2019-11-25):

#ifndef _MAIN_H_
#define _MAIN_H_

#define main_flag GPIOR1
#define SAMPLESTEPDOWNRIGHT 0   //new sample for StepUp Converter available
#define SAMPLESTEPDOWNLEFT  1   //new sample for StepDown Converter available
#define SAMPLETEMPERATURE   2   //new sample for Temperature available
#define USIRXDONE           3
#define WATCHDOG            4
#define COMRXDONE           5

#define TEMPOFFS    (uint16_t*)0
#define LEFTGAIN    (uint8_t*)2
#define RIGHTGAIN   (uint8_t*)3

#endif

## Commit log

2017-01-15 reworked limiter (reduced flickering), improved power management and cable communication
    [light_distribution.ods]
2017-01-20 added cloned modes to use both drivers for spot or flood
2017-01-21 added configuration helper file
    [State_Config_Helper.ods]
2017-01-23 fixed com lockup bug and flickering with cold battery
    [comreloaded.c, main.c]
2017-01-30 added led configuration detection and user manual
2017-01-31 added sensor offset calibration
2017-02-22 added brake detection (still experimental)
2017-02-27 added reverse polarity protection and led board
    [Helena_LED_Board_sd.kicad_pcb, Helena_LED_Board_sd.sch, Helena_base_sd.kicad_pcb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]
2018-11-16 added independent configurable current limit
    [Helena_base_sd.kicad_pcb, Helena_ctrl.kicad_pcb]
2019-02-26 updated control board
    [Helena_ctrl.kicad_pcb, Helena_ctrl.sch]
2019-10-29 Hardware update for better compatibility with KD2 style lights
    [Helena_LED_Board_sd.kicad_pcb, Helena_LED_Board_sd.sch, Helena_base_sd-2019-07-31-09-47-23.sch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]
2019-11-04 light module rework including new limiter, prepared 1 and 3 cell support
    [comreloaded.c, main.c]
2019-11-07 Setup changed (and extended) from enumeration to flags
    [State_Config_Helper.ods]
2019-11-14 implemented daisy chain feature
    [State_Config_Helper.ods]
2019-11-15 added taillight and brake indicator
2019-11-16 added low power motion interrupt to wakeup lamp when moving
2019-11-22 debug report on notification enable, hmi interface handles remote buttons, prepared btle to read inclination of connected light
2019-11-25 added driver calibration over i2c
2019-12-03 fixed failed garbage collection bug, driver firmware update, doku update
    [main.c]
2021-04-18 added support for R51 remote
    [State_Config_Helper.ods]
2021-04-21 status led blinking
2021-04-22 added battery soc and taillight power to measurement notification
2021-04-23 factory reset with button
    [main.c]
2022-07-24 add support for Pearl/Auviso Remote, bugfixes, build instructions, ...
    [AVRootloader.asm]
2024-06-17 v3 alpha
    [Helena_LED_Board_sd.kicad_pcb, Helena_LED_Board_sd.sch, XHP35_XHP50_KD2.kicad_pcb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]
2025-06-22 fixed hard fault when relaying mode from com interface
    [comreloaded.c]
